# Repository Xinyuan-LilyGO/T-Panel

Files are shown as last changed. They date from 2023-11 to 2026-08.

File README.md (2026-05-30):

<h1 align="center">T-Panel</h1>

## **English** | [Chinese](./README_CN.md)

<!-- [![Release](https://img.shields.io/github/v/release/Xinyuan-LilyGO/T-Panel?style=flat-square)](https://github.com/Xinyuan-LilyGO/T-Panel/releases) -->




<p align="center">
  T-Panel product photo
</p>

## Overview

T-Panel is a compact smart-home control panel with an **ESP32-S3** main controller and a **480 x 480 RGB touch display**. It integrates local UI rendering, SD card storage, long-distance field-bus communication, and an **ESP32-H2** wireless coprocessor interface.

## Directory

- [Overview](#overview)
- [Hardware Versions](#hardware-versions)
- [Preview](#preview)
- [Supported Frameworks](#supported-frameworks)
- [Quick Start](#quick-start)
- [Hardware Modules](#hardware-modules)
- [Pin Overview](#pin-overview)
- [Project Materials](#project-materials)
- [FAQ](#faq)

## Hardware Versions

| Version | Date | Description |
| :---: | :---: | --- |
| T-Panel V1.0-V1.1 | 2023-11-23 | Initial hardware version |
| T-Panel V1.2 | 2023-12-11 | RS485 module changed to replaceable RS485/CAN module |
| T-Panel V1.3 | 2024-05-08 | Structure update |

## Preview

<p align="center">
  T-Panel front view
  T-Panel side view
  T-Panel back view
</p>

## Supported Frameworks

| Framework | Status | Version |
| --- | --- | --- |
| ESP-IDF | Recommended | `>= v5.5.4` |

## Quick Start

### Build With ESP-IDF

Install ESP-IDF first. For environment setup, refer to the official guide:
[ESP-IDF Get Started](https://docs.espressif.com/projects/esp-idf/en/latest/esp32s3/get-started/index.html)

```bash
idf.py set-target esp32s3
idf.py menuconfig
idf.py build
idf.py flash monitor
```

Select one of the following examples in `menuconfig`, then rebuild the project.

```text
Example Configuration
`-- Select the example to build
```

| Example | Description |
| --- | --- |
| [`screen`](./main/examples/screen) | Basic RGB LCD bring-up example |
| [`screen_lvgl`](./main/examples/screen_lvgl) | LVGL 9.5 display startup example |
| [`screen_lvgl_touch_draw`](./main/examples/screen_lvgl_touch_draw) | LVGL touch drawing example |
| [`sd`](./main/examples/sd) | SD card mount and file-system test |
| [`rs485_can`](./main/examples/rs485_can) | Field-bus transfer test example |
| [`general_test`](./main/examples/general_test) | Integrated factory test UI |

The following firmware is prebuilt.

To flash prebuilt firmware, refer to Espressif's official [ESP firmware online flashing platform guide](https://docs.espressif.com/projects/esp-techpedia/zh_CN/latest/esp-friends/get-started/try-firmware/try-firmware-platform.html).

| Firmware | Flash Address | Description |
| --- | --- | --- |
| [`general_test`](<./firmware/[t-panel_v1.2][general_test]>) | `0x0` | T-Panel V1.2 `general_test` factory test firmware |

## Hardware Modules

### 1. MCU

- MCU1: ESP32-S3
- PSRAM: 8 MB
- Flash: 16 MB
- Related documents:
  - [Espressif technical documents](https://www.espressif.com/en/support/documents/technical-documents)

- MCU2: ESP32-H2-MINI-1
- Flash: 4 MB
- Related documents:
  - [ESP32-H2-MINI-1 datasheet](https://www.espressif.com/sites/default/files/documentation/esp32-h2-mini-1_mini-1u_datasheet_en.pdf)

### 2. Display

- Model: YDP395BT001
- Size: 3.95 inch
- Resolution: 480 x 480
- Type: IPS
- Driver IC: ST7701S
- Bus: SPI initialization + RGB data bus
- Related documents:
  - [YDP395BT001-V2](./docs/YDP395BT001-V2.pdf)
  - [ST7701S](./docs/ST7701S_SPEC_V1.4.pdf)

### 3. Touch

- Chip: CST3240
- Bus: I2C
- Related documents:
  - [HYNITRON-CST3240_V1.0](./docs/HYNITRON-CST3240_V1.0.pdf)

### 4. IO Expansion

- Chip: XL9535
- Bus: I2C
- Usage: LCD reset/control, SPI control and auxiliary GPIO
- Related documents:
  - [XL9535](./docs/XL9535.pdf)

### 5. SD Card Slot

- Bus: SPI
- File system: FATFS

### 6. RS485 / CAN

- RS485 bus: UART
- CAN bus: TWAI
- Related documents:
  - [EBYTE-RSM485MT5V](./docs/EBYTE-RSM485MT5V.pdf)
  - [TD501MCANFD_MORNSUN](./docs/TD501MCANFD_MORNSUN.pdf)

> [!IMPORTANT]
> T-Panel V1.0-V1.1 ships with RS485 by default; T-Panel V1.2-V1.3 uses a replaceable RS485/CAN module.

## Pin Overview

Pin definitions are provided in [`t_panel_config.h`](./libraries/private_library/t_panel_config.h).

## Project Materials

| Document | Description |
| --- | --- |
| [`T-Panel_V1.2.pdf`](./project/T-Panel_V1.2.pdf) | Hardware project PDF |
| [`structure`](./structure) | Enclosure structure materials |

## FAQ

<details>
<summary>Q. Why does my board continuously fail to flash?</summary>

A. Please hold down the `BOOT` button and try downloading the program again.

</details>

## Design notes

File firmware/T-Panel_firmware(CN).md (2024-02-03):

<!--
 * @Description: None
 * @version: V1.0.0
 * @Author: LILYGO_L
 * @Date: 2023-09-12 18:12:36
 * @LastEditors: LILYGO_L
 * @LastEditTime: 2024-02-03 14:38:37
 * @License: GPL 3.0
-->
<h1 align = "center">T-Panel 初始测试 firmware 说明</h1>

## 适用版本：[T-Panel_V1.0]、[T-Panel_V1.1]
### <br />更改日志[ESP32S3]:
#### T-Panel_Test_ESP32S3_firmware_V1.0.0: 初始版本
#### T-Panel_Test_ESP32S3_firmware_V1.0.1:
    1.修复了整板重新上电后ESP32H2需要手动复位才有返回信息的问题
    2.修复了点击“Please touch me!”后进入主界面，屏幕出现大量ESP32H2初始化信息的问题
#### T-Panel_Test_ESP32S3_firmware_V1.0.2:
    1.新增屏幕边缘测试
#### T-Panel_Test_ESP32S3_firmware_V1.0.3:
    1.修复屏幕边缘测试部分时序不对检测失败的问题
#### T-Panel_Test_ESP32S3_firmware_V1.0.4:
    1.调整屏幕背光PWM为1Khz

### <br />更改日志[ESP32H2]:
#### T-Panel_Test_ESP32H2_firmware_V1.0.0: 初始版本
#### T-Panel_Test_ESP32H2_firmware_V1.0.1:
    1.修复了ESP32H2返回计数超过100后返回乱码的问题

## <br />适用版本：[T-Panel_V1.2]

### <br />更改日志[ESP32S3]:

#### [ESP32S3][T-Panel_V1.2][T-Panel_Test_V1_2]_firmware_V1.0.0(RS485): 初始版本

#### <br />[ESP32S3][T-Panel_V1.2][T-Panel_Test_V1_2]_firmware_V1.0.0(CAN): 初始版本

### <br />更改日志[ESP32H2]:
#### [ESP32H2][T-Panel_V1.2][ESP32H2_Test]_firmware_V1.0.2: 初始版本

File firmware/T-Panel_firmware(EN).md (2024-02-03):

<!--
 * @Description: None
 * @version: V1.0.0
 * @Author: LILYGO_L
 * @Date: 2023-09-12 18:12:36
 * @LastEditors: LILYGO_L
 * @LastEditTime: 2024-02-03 14:41:54
 * @License: GPL 3.0
-->
<h1 align = "center">T-Panel original testing firmware instructions</h1>

## Applicable Version: [T-Panel_V1.0],[T-Panel_V1.1]

### <br />Change Log[ESP32S3]:

#### T-Panel_Test_ESP32S3_firmware_V1.0.0: Original
#### T-Panel_Test_ESP32S3_firmware_V1.0.1:
    1. Fixed the issue of ESP32H2 needing manual reset after powering on the whole board again to return information.
    2. Fixed the problem of displaying a large number of ESP32H2 initialization messages on the screen after clicking "Please touch me!" and entering the main interface.
#### T-Panel_Test_ESP32S3_firmware_V1.0.2:
    1.Newly added screen edge testing
#### T-Panel_Test_ESP32S3_firmware_V1.0.3:
    1.Fix the issue of incorrect timing in the screen edge testing section and detection failure
#### T-Panel_Test_ESP32S3_firmware_V1.0.4:
    1.Adjust the screen backlight PWM to 1 Khz

### <br />Change Log[ESP32H2]:
#### T-Panel_Test_ESP32H2_firmware_V1.0.0: Original
#### T-Panel_Test_ESP32H2_firmware_V1.0.1:
    1. Fixed the issue of returning garbled characters when ESP32H2 returns a count exceeding 100.

## <br />Applicable Version: [T-Panel_V1.2]

### <br />Change Log[ESP32S3]:

#### [ESP32S3][T-Panel_V1.2][T-Panel_Test_V1_2]_firmware_V1.0.0(RS485): Original

#### <br />[ESP32S3][T-Panel_V1.2][T-Panel_Test_V1_2]_firmware_V1.0.0(CAN): Original

### <br />Change Log[ESP32H2]:
#### [ESP32H2][T-Panel_V1.2][ESP32H2_Test]_firmware_V1.0.2: Original

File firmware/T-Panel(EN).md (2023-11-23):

<!--
 * @Description: None
 * @version: V1.0.0
 * @Author: LILYGO_L
 * @Date: 2023-09-12 18:12:36
 * @LastEditors: LILYGO_L
 * @LastEditTime: 2023-11-23 15:03:34
 * @License: GPL 3.0
-->
## T-Panel instructions

### T-Panel_ESP32S3 Change Log:
#### T-Panel_Test_ESP32S3_firmware_V1.0.0:Original
#### T-Panel_Test_ESP32S3_firmware_V1.0.1:
    1. Fixed the issue of ESP32H2 needing manual reset after powering on the whole board again to return information.
    2. Fixed the problem of displaying a large number of ESP32H2 initialization messages on the screen after clicking "Please touch me!" and entering the main interface.

### T-Panel_Test_ESP32H2 Change Log:
#### T-Panel_Test_ESP32H2_firmware_V1.0.0:Original
#### T-Panel_Test_ESP32H2_firmware_V1.0.1:
    1. Fixed the issue of returning garbled characters when ESP32H2 returns a count exceeding 100.

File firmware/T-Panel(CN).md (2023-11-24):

<!--
 * @Description: None
 * @version: V1.0.0
 * @Author: LILYGO_L
 * @Date: 2023-09-12 18:12:36
 * @LastEditors: LILYGO_L
 * @LastEditTime: 2023-11-23 15:01:30
 * @License: GPL 3.0
-->
## T-Panel firmware 说明

### T-Panel_ESP32S3更改日志:
#### T-Panel_Test_ESP32S3_firmware_V1.0.0:初始版本
#### T-Panel_Test_ESP32S3_firmware_V1.0.1:
    1.修复了整板重新上电后ESP32H2需要手动复位才有返回信息的问题
    2.修复了点击“Please touch me!”后进入主界面，屏幕出现大量ESP32H2初始化信息的问题

### T-Panel_Test_ESP32H2更改日志:
#### T-Panel_Test_ESP32H2_firmware_V1.0.0:初始版本
#### T-Panel_Test_ESP32H2_firmware_V1.0.1:
    1.修复了ESP32H2返回计数超过100后返回乱码的问题

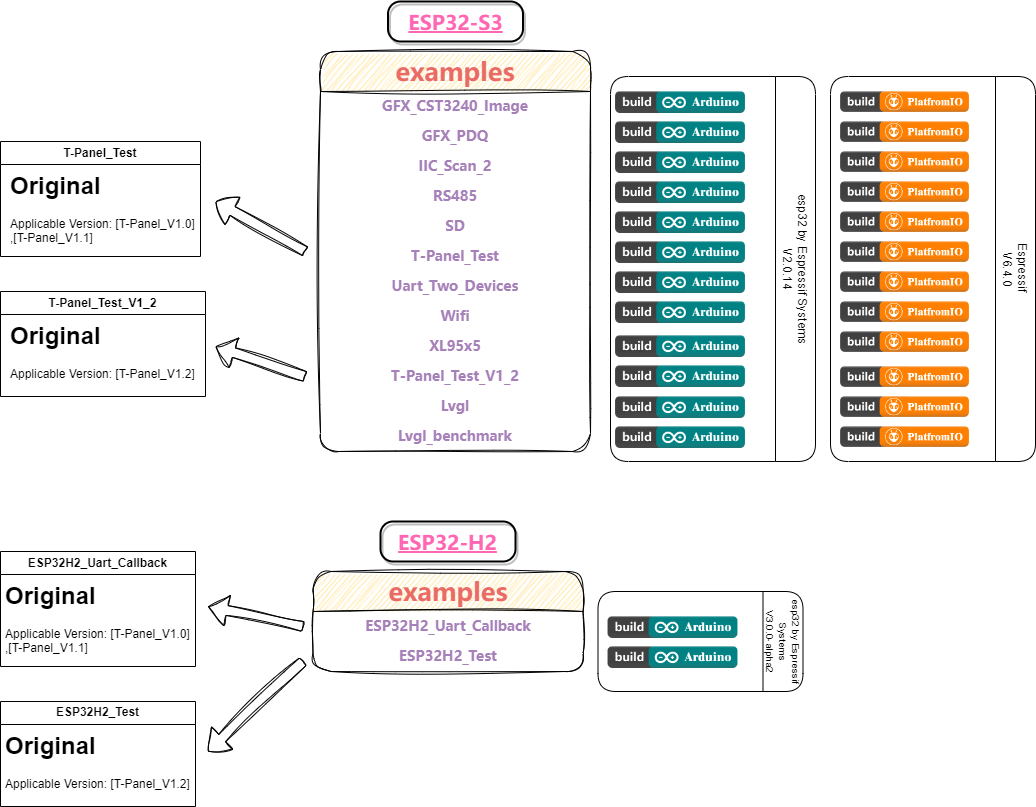
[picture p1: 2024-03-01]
image/T-Panel_Example_Support.png

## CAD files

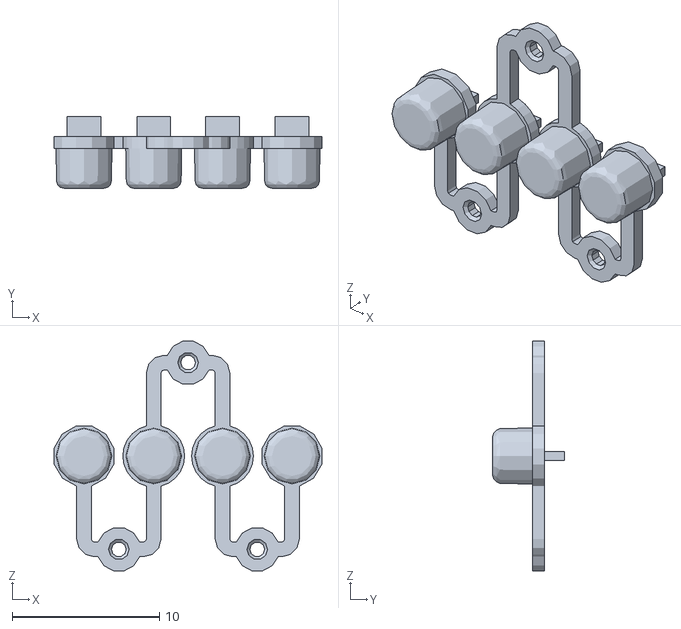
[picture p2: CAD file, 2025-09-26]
structure/T-Panel_shell_202509261512/4.stl
18.2 x 4.85 x 15.6

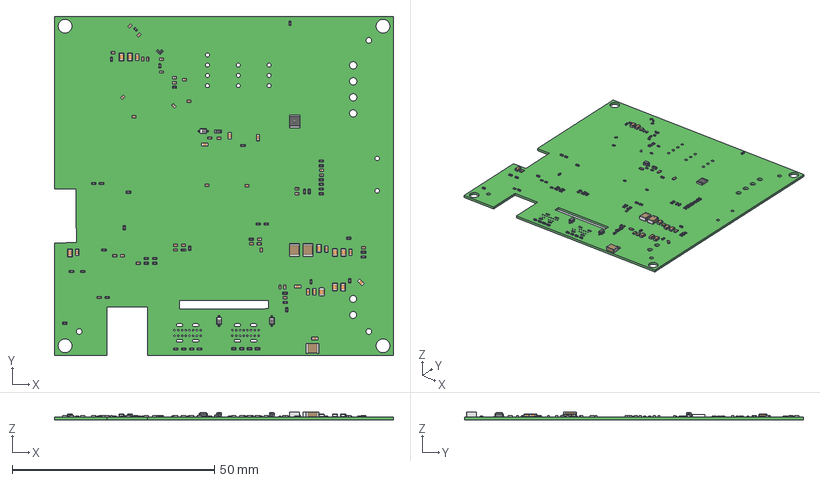
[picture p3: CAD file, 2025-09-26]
structure/T-Panel_V1.2.step
83.8 x 83.8 x 2.10 mm
L0402 x 3
0402_SMD_Capacitor x 37
User_Library-0603_SMD_Capacitor x 12
User_Library-0805_SMD_Capacitor x 9
User_Library-cap_1210_lowprofile x 3
User_Library-RES_1005-0402 x 47
SOD323 x 3
User_Library-RES_1609-0603
User_Library-R_1210

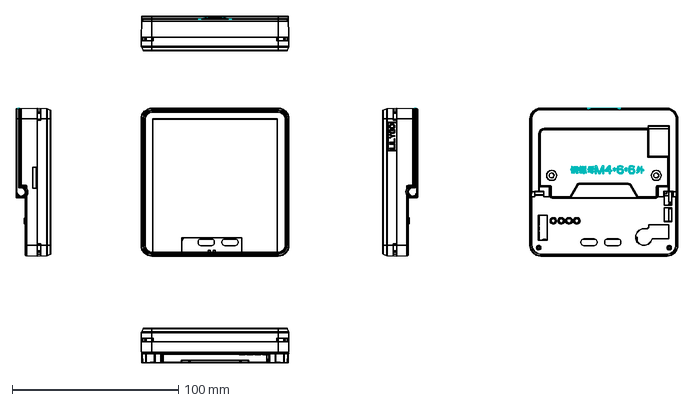
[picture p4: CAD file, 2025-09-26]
structure/T-Panel_shell.dxf
398.3 x 208.8 mm

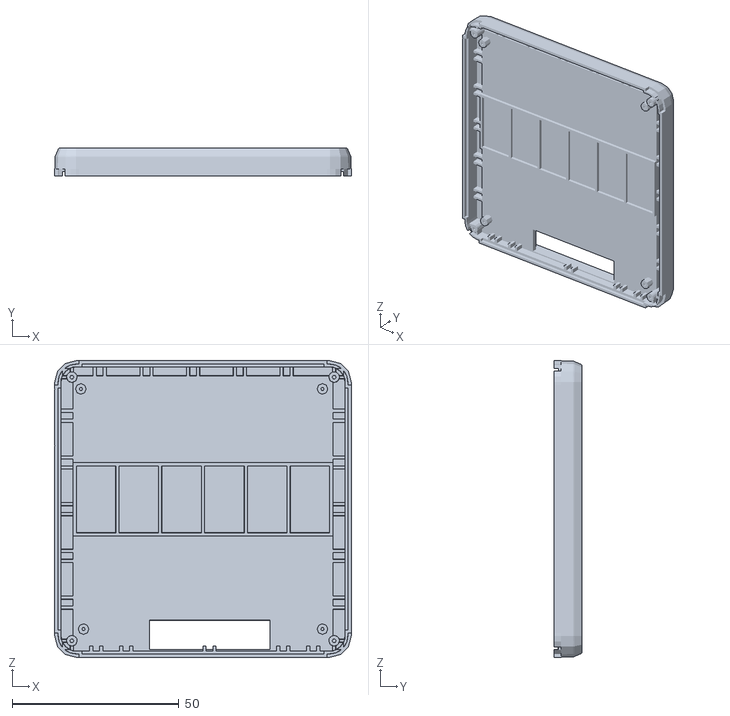
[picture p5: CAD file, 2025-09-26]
structure/T-Panel_shell_202509261512/1.stl
89.0 x 8.45 x 89.0

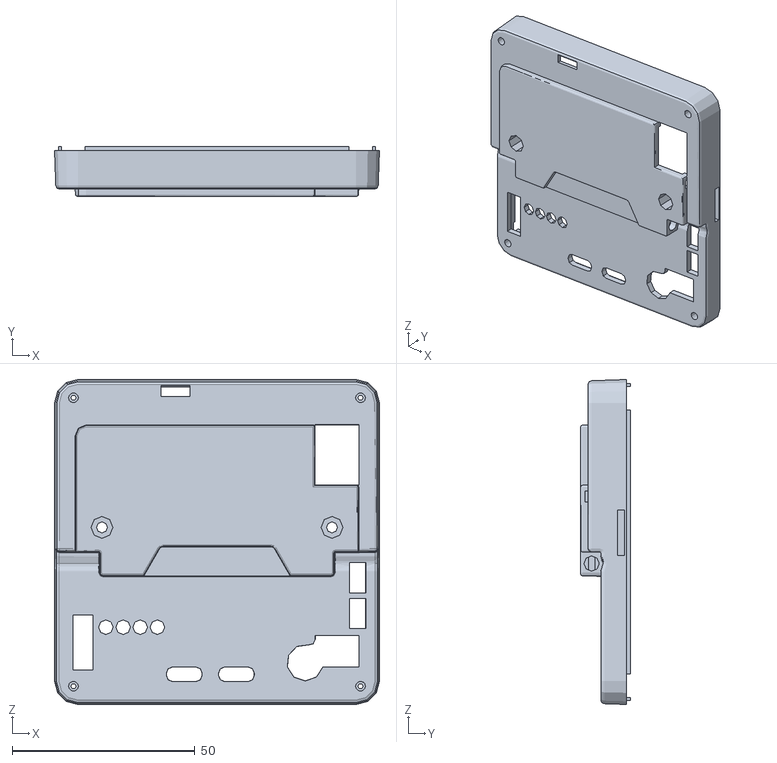
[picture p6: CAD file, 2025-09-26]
structure/T-Panel_shell_202509261512/2.stl
89.0 x 13.6 x 89.0

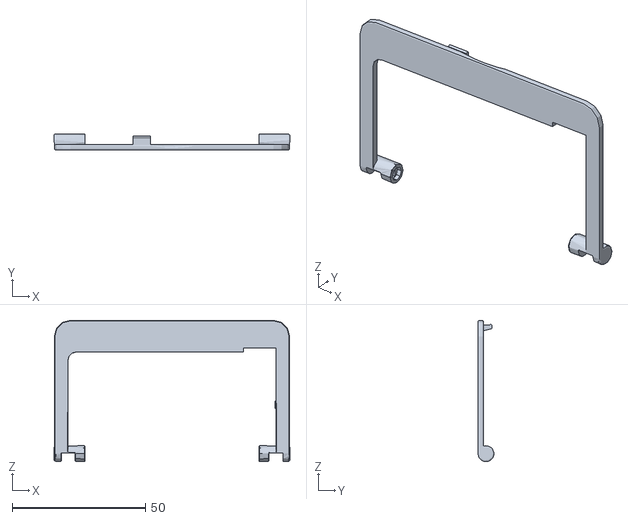
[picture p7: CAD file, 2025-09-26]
structure/T-Panel_shell_202509261512/3.stl
88.5 x 6.00 x 53.0

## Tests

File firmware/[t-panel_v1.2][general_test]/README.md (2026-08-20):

# Firmware Modification Log

## 202608200958
### Changed firmware
- `[t-panel_v1.2][general_test]_firmware_202608200958`
### Change content
- 修复can总线异常错误停止，防止can总线在正常通信连接的情况错误停止

## 202606131107
### Changed firmware
- `[t-panel_v1.2][general_test]_firmware_202606131107`
### Change content
- 删除rs485发送界面显示的无用crc error和seq error信息

## 202606131047
### Changed firmware
- `[t-panel_v1.2][general_test]_firmware_202606131047`
### Change content
- 将rs485校验数据改为使用crc16校验方式，修改rs485 can页面数据显示

## 202605301133
### Changed firmware
- `[t-panel_v1.2][general_test]_firmware_202605301133`
### Change content
- 新版本测试更新

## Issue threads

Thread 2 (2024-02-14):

Version?

Bwooce, 2024-02-14:
Got a shortcut so I can tell which board version I have? I assume since mine has no CAN then it's v1 or v1.1?  (I can't see any silkscreen version)

Llgok, 2024-02-29:
Two versions are currently available: T-Panel_V1.0 and T-Panel_V1.2 The hardware of the two versions is different, and the corresponding software is also different. You can find the relevant macro definitions in "./Mylibrary/pin_config.h"

1.T-Panel_V1.0 version only has an RS485 chip. Uncomment "#define T_Panel_V1_0_RS485".
2.T-Panel_V1.2 version can choose either an RS485 chip or a CAN bus chip based on the module inserted on the board. Uncomment "#define T_Panel_V1_2_RS485" or "#define T_Panel_V1_2_CAN" accordingly.

Llgok, 2024-02-29:
> Got a shortcut so I can tell which board version I have? I assume since mine has no CAN then it's v1 or v1.1? (I can't see any silkscreen version)

Two versions are currently available: T-Panel_V1.0 and T-Panel_V1.2 The hardware of the two versions is different, and the corresponding software is also different. You can find the relevant macro definitions in "./Mylibrary/pin_config.h"

1.T-Panel_V1.0 version only has an RS485 chip. Uncomment "#define T_Panel_V1_0_RS485".
2.T-Panel_V1.2 version can choose either an RS485 chip or a CAN bus chip based on the module inserted on the board. Uncomment "#define T_Panel_V1_2_RS485" or "#define T_Panel_V1_2_CAN" accordingly.

Bwooce, 2024-02-29:
Thanks! I have an RS485 version but not sure if it's 1.0 or 1.2, how can I tell? There's no version number written on the physical board?

Llgok, 2024-02-29:
> Thanks! I have an RS485 version but not sure if it's 1.0 or 1.2, how can I tell? There's no version number written on the physical board?

The replaceable long-distance transmission module is version 1.2.
The non-replaceable long-distance transmission module is version 1.0.

The following diagram is of version 1.2.
![Uploading IMG_20240229_175451.jpg…]()

Llgok, 2024-02-29:
> Thanks! I have an RS485 version but not sure if it's 1.0 or 1.2, how can I tell? There's no version number written on the physical board?

The replaceable long-distance transmission module is version 1.2.
The non-replaceable long-distance transmission module is version 1.0.

The following diagram is of version 1.2.
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

Closed 2024-05-07.

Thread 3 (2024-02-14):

RS485 information

Bwooce, 2024-02-14:
Small questions, after reading the RSM485 datasheet:
* S_GND is the isolated ground, so for RS485 GND wire?
* D_GND is for the outer cable shield? or for non-isolated RS485 GND?
* Is there a link to enable RS485 termination resistors? Or none on this board?

Nice board.

Llgok, 2024-02-29:
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

S_GND is the isolation voltage output negative pole of the module, usually used for connecting the ground wire of the signal line, mainly for transmitting data signals.
D_GND is the ground wire of the digital circuit, used to connect the ground wire in the digital circuit.

The T-Panel_V1.0 version module RSM485MT5V has built-in terminal resistance, so there is no need to connect terminal resistance on the PCB and externally.
The T-Panel_V1.2 version module does not have terminal resistance, so a 120-ohm terminal resistance is added to the PCB to ensure stable signal transmission.

Closed 2024-05-07.

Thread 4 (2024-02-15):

I2C Arduino MPC9600

neilaw, 2024-02-15:
I am trying to get the T-Panel to connect to an Adruino MPC9600 thermocouple amplifier without any success.
I can connect to other I2C devices ok, just not the Adafruit MPC9600.
I tried connecting the T-panel to a 24vdc power supply to see if it was a power issue, but it didn't make any diffrence.
Using the IIC Scanner, it momentarily showed the address. so it seems to be working, but not sure why it doesn't see it all the time.
I tried chenging the address in the MPC9600, but it didn't make any diffrence.
Any Ideas?

Llgok, 2024-02-29:
> Adruino MPC9600

Can you check if the power supply voltage for the MCP9600 device is normal?

Closed 2024-05-07.

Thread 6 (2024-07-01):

Readme needs clarification

manmountain, 2024-07-01:
I needed to install esp32 version 2.0.17 from boards manager to get the lvgl examples to build. That needs to be added to the readme.

And also, what is the recommended setting for Partition Scheme?

Llgok, 2024-07-10:
@manmountain
In the "QuickStart" section of the README.md file, the Partition Scheme is explained.

Closed 2024-07-19.

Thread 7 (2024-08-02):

CAD files available?

shyndman, 2024-08-02:
### IDE and version or firmware

n/a

### Operating System

n/a

### Description

Hello there,

I was wondering if you might release step files for the T-Panel's hardware variants. I'd really like to design some accurate cases for this thing. :)

PS. Thank you for the wonderful device. I'm having a lot of fun with it, and learning a lot.
PPS. Modelled a little leanback stand for use during development ([Printables link](https://www.printables.com/model/962461-lilygo-t-panel-s3-development-stand)), but without step files it's slightly wonky.

### Sketch

```cpp
n/a
```

### Debug Message

```plain
n/a
```

### Other steps to Reproduce

_No response_

Llgok, 2024-11-21:
@shyndman
Updated [T-Panel_V1.2 CAD](https://github.com/Xinyuan-LilyGO/T-Panel/blob/arduino-esp32-libs_V2.0.14/structure/T-Panel_V1.2.dxf) Drawings

Llgok, 2025-01-02:
Closed due to prolonged inactivity.

Closed 2025-01-02.

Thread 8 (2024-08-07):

Please clarify details on CANFD

TobyLies, 2024-08-07:
### IDE and version or firmware

T-Panel_V1.3 CANFD

### Operating System

T-Panel_V1.3 CANFD

### Description

Can you give some clarification on the CANFD version of the board? Is it CAN (Controller Area Network) or is it CAN FD (Flexible Data)? If it's CANFD, I gather that TWAI isn't compatible with CANFD?

I don't see any other reference to CANFD in the github.

I want to use the T-Panel to read CAN messages in a car, and display info derived from it. Does the T-Panel both send and receive CAN messages? Or does it require an external board?

### Sketch

```cpp
n/a
```

### Debug Message

```plain
n/a
```

### Other steps to Reproduce

_No response_

aokhrimenko, 2024-09-02:
What CAN transceiver do you use on this board? I see nothing on schematics.

viniciusro, 2024-09-02:
TD501MCANFD

Llgok, 2024-09-03:
> What CAN transceiver do you use on this board? I see nothing on schematics.

@aokhrimenko
@viniciusro
The following is the data manual for the CAN module.
[TD501MCANFD_MORNSUN](https://github.com/Xinyuan-LilyGO/T-Panel/blob/arduino-esp32-libs_V2.0.14/information/TD501MCANFD_MORNSUN.pdf)

Llgok, 2024-09-10:
Closed due to lack of response for a long time.

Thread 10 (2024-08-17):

Adding WIFI to Lvgl example will make it crash.

viniciusro, 2024-08-17:
### IDE and version or firmware

framework = arduino, platform = espressif32, board = dfrobot_firebeetle2_esp32s3

### Operating System

Windows 10

### Description

Adding simple wifi connect to setup will make the example crash:

### Sketch

```cpp
`    // Connect to Wi-Fi
    WiFi.mode(WIFI_MODE_STA);
    WiFi.begin(ssid, password);
    while (WiFi.status() != WL_CONNECTED)
    {
        delay(5);
        Serial.print(".");
    }
    Serial.println("Connected to WiFi");
    Serial.println(WiFi.localIP());`
```

### Debug Message

```plain
Ciallo
.................Connected to WiFi
192.168.188.75
Found xl9535
Guru Meditation Error: Core  1 panic'ed (LoadProhibited). Exception was unhandled.

Core  1 register dump:
PC      : 0x42005458  PS      : 0x00060f30  A0      : 0x82005575  A1      : 0x3fcebb50
A2      : 0x3fcebb74  A3      : 0xffffffff  A4      : 0x00000000  A5      : 0x000000ff
A6      : 0xffffffff  A7      : 0x000000ff  A8      : 0x820053b6  A9      : 0x3fcebb30
A10     : 0x00000000  A11     : 0x3fcebbc0  A12     : 0x3fcebbb8  A13     : 0x00000000
A14     : 0x00000001  A15     : 0x3fceba4c  SAR     : 0x0000001f  EXCCAUSE: 0x0000001c
EXCVADDR: 0x00000017  LBEG    : 0x400570e8  LEND    : 0x400570f3  LCOUNT  : 0x00000000

Backtrace: 0x42005455:0x3fcebb50 0x42005572:0x3fcebb70 0x42007473:0x3fcebbb0 0x42007c0b:0x3fcebc60 0x4209faa2:0x3fcebc90 0x420053c7:0x3fcebcb0 0x42005572:0x3fcebcd0 0x4200c5cd:0x3fcebd10 0x4200c699:0x3fcebd60 0x4200c9d2:0x3fcebde0 0x4200cb03:0x3fcebe10 0x4200d5bf:0x3fcebee0 0x420198e8:0x3fcebf30 0x420024c3:0x3fcebf60 0x4202db09:0x3fcebf80

ELF file SHA256: 20011c7cb8b2c78f

Rebooting...
ESP-ROM:esp32s3-20210327
Build:Mar 27 2021
rst:0xc (RTC_SW_CPU_RST),boot:0x8 (SPI_FAST_FLASH_BOOT)
Saved PC:0x420a232a
SPIWP:0xee
mode:DIO, clock div:1
load:0x3fce3808,len:0x4bc
load:0x403c9700,len:0xbd8
load:0x403cc700,len:0x2a0c
entry 0x403c98d0
```

### Other steps to Reproduce

After initialization and connection the WIFI is not used in any other place.
Same problem with "Lvgl_benchmark.ino"
As reference, with T-Encoder Pro, using lvgl and WIFI will work with no problem.

VolosR, 2024-08-23:
I have identical problem. Lvgl example will not work if board is connected to wifi.

nikthefix, 2024-08-24:
@viniciusro

As an experiment try replacing

lv_disp_draw_buf_init(&draw_buf, buf_1, buf_2, 48 * 1024 * 2);
with
lv_disp_draw_buf_init(&draw_buf, buf_1, NULL, 2 * 480 * 10);

nik

viniciusro, 2024-08-25:
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

Hey nik,

Thanks for the idea, it works!
Now I can sed UDP packages and display data on the screen.

I will investigate further the second buffer.

```cpp
    // lv_disp_draw_buf_init(&draw_buf, buf_1, buf_2, 48 * 1024 * 2);
    lv_disp_draw_buf_init(&draw_buf, buf_1, NULL, 2 * 480 * 10);
```

- draw_buf -- pointer lv_disp_draw_buf_t variable to initialize

- buf1 -- A buffer to be used by LVGL to draw the image. Always has to specified and can't be NULL. Can be an array allocated by the user. E.g. static lv_color_t disp_buf1[1024 * 10] Or a memory address e.g. in external SRAM

- buf2 -- Optionally specify a second buffer to make image rendering and image flushing (sending to the display) parallel. In the disp_drv->flush you should use DMA or similar hardware to send the image to the display in the background. It lets LVGL to render next frame into the other buffer while previous is being sent. Set to NULL if unused.

- size_in_px_cnt -- size of the buf1 and buf2 in pixel count.

nikthefix, 2024-08-25:
@viniciusro
Thanks for letting me know that it worked.
I made conservative assumptions as I didn't know how you defined your buf_1 but if you sized it to contain 16 bit/px then you could further reduce the lv draw buffer to just:

 lv_disp_draw_buf_init(&draw_buf, buf_1, NULL, 480 * 10); //single buffer, line px width, number of lines per write.

In my experience 10 to 40 lines per write is good use of resources for the 480x480 display and keeps things 'ticking' over nicely.
I have personally not seen any advantage to using double buffering with st7701 / esp32-s3 but your mileage may vary.

Volos Projects released a video this morning using the T-Panel:

https://www.youtube.com/watch?v=6-7ZjbE4Qqc

nik

Llgok, 2024-09-10:
Closed due to lack of response for a long time.

Closed 2024-09-10.

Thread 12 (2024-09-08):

Screen turns black every couple seconds when running the lvgl demo

8lue5ky, 2024-09-08:
### IDE and version or firmware

PlatformIO 6.1.15/3.4.4

### Operating System

Windows10

### Description

Hi

I downloaded this repo and uploaded the lvgl example (uncomment "default_envs = Lvgl" in platformIO).

The problem is that the screen turns black every couple of seconds when touching the screen. Same when trying to upload my own code from square line studio.

Interesting is that when the serial monitor is opened, it works correct (see "get_int" in the console when touching the screen).

Do you have any idea why this happens?

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

The Lvgl_benachmark works without issues, both, with and without serial monitor.

### Sketch

```cpp
Lvgl example from your repo T-Panel-arduino-esp32-libs_V2.0.14.
```

### Debug Message

```plain
None, because it doesn't happen when the serial monitor is opened.
```

### Other steps to Reproduce

_No response_

8lue5ky, 2024-09-08:
I found the issue.

When removing the `Serial.println("get_int");` in the `attachInterrupt()`, the issue is gone.

I assume that the `Serial.println` takes to much time in the interrupt handler.

Closed 2024-09-08.

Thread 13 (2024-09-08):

LVGL Switch click not working properly

8lue5ky, 2024-09-08:
### IDE and version or firmware

PlatformIO 6.1.15/3.4.4

### Operating System

Windows10

### Description

When using your LVGL file from the examples template as base with my own UI export files from square line studio, the toggle switch is somehow not working every time when clicked.

I made a small recording of the behavior:

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

It looks like the button is sometime clicked multiple times when touched once.

I saw that VolosR added some kind of debounce mechanism in his project [TPanelNetwork](https://github.com/VolosR/TPanelNetwork/blob/main/Panel/Panel.ino). But with that workaround, some other controls (e.g. Arc) are not really usable anymore.

Do you have any ideas how to improve this?

### Sketch

```cpp
Lvgl from examples folder with a toggle button.
```

### Debug Message

```plain
None.
```

### Other steps to Reproduce

_No response_

Llgok, 2024-09-10:
@8lue5ky
Hello, could you provide the code for the touch callback function in your LVGL project? Or, you could share the entire original file of your project, which would be more conducive to troubleshooting and resolving our issues.

8lue5ky, 2024-09-10:
I creates a copy of the Lvgl example with a screen just containing a toggle switch and a arc.

[Commit with example](https://github.com/8lue5ky/T-Panel/commit/4f4b5f497aa39810fa4b51a0713a6ffe2b73741b)

It should look like this:
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

Llgok, 2024-09-11:
@8lue5ky
I browsed through your code and found there were indeed issues with touch functionality. I've already fixed this problem. You can try replacing the following touch-related code:

```C++
/*Read the touchpad*/
void my_touchpad_read(lv_indev_drv_t *indev_drv, lv_indev_data_t *data)
{
    if (Touch_Int_Flag == true)
    {
        touch.read();
        TP_Point t = touch.getPoint(0);

        if ((touch.getPointNum() == 1) && (t.pressure > 0) && (t.state != 0))
        {
            data->state = LV_INDEV_STATE_PR;

            /*Set the coordinates*/
            data->point.x = t.x;
            data->point.y = t.y;

            // Serial.printf("Touch X: %d Y: %d", t.x, t.y);
            // Serial.printf("Static: %d", t.state);
            // Serial.printf("Pressure: %d", t.pressure);
        }

        Touch_Int_Flag = false;
    }
    else
    {
        data->state = LV_INDEV_STATE_REL;
    }
}
```

8lue5ky, 2024-09-12:
Thank you very much. It works now perfectly fine 👍

Closed 2024-09-12.

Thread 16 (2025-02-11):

STEP files for a custom enclosure

ArthurAfterBurnerDesign, 2025-02-11:
Hello,

I've find the dxf file in the enclosure [here](https://github.com/Xinyuan-LilyGO/T-Panel/blob/arduino-esp32-libs_V2.0.14/structure/T-Panel_V1.2.dxf), but can we please get a .step model of the enclosure and board, please ?

Thanks

Llgok, 2025-09-26:
@ArthurAfterBurnerDesign
This is the 3D image of the board. [T-Panel_V1.2.step](https://github.com/Xinyuan-LilyGO/T-Panel/blob/arduino-esp32-libs_V2.0.14/structure/T-Panel_V1.2.step)

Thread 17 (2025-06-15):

pin_config.h: No such file or directory

jsonslim, 2025-06-15:
### Operating System

Windows 10

### IDE

Arduino IDE

### Software Package Version

last versions

### Description

Hello, I'm trying to run the "Lvgl" example from  this repo. The first error message is "pin_config.h: No such file or directory".  I couldn't find this file anywhere in the repo/zip file. Please, add it - with the correct pin numbers and so on

### Sketch

```cpp
/*
 * @Description: LVGL
 * @Author: LILYGO_L
 * @Date: 2023-09-22 11:59:37
 * @LastEditTime: 2024-11-21 11:42:10
 * @License: GPL 3.0
 */
// #define TOUCH_MODULES_GT911
// #define TOUCH_MODULES_CST_SELF
#define TOUCH_MODULES_CST_MUTUAL
// #define TOUCH_MODULES_ZTW622
// #define TOUCH_MODULES_L58
// #define TOUCH_MODULES_FT3267
// #define TOUCH_MODULES_FT5x06

#include "lvgl.h"
#include "Arduino_GFX_Library.h"
#include "pin_config.h"
#include "TouchLib.h"
#include "gui_guider.h"
#include "events_init.h"
#include "custom.h"

volatile bool Touch_Int_Flag = false;

lv_ui guider_ui;

TouchLib touch(Wire, TOUCH_SDA, TOUCH_SCL, CST3240_ADDRESS);

Arduino_DataBus *bus = new Arduino_XL9535SWSPI(IIC_SDA /* SDA */, IIC_SCL /* SCL */, -1 /* XL PWD */,
                                               XL95X5_CS /* XL CS */, XL95X5_SCLK /* XL SCK */, XL95X5_MOSI /* XL MOSI */);
Arduino_ESP32RGBPanel *rgbpanel = new Arduino_ESP32RGBPanel(
    -1 /* DE */, LCD_VSYNC /* VSYNC */, LCD_HSYNC /* HSYNC */, LCD_PCLK /* PCLK */,
    LCD_B0 /* B0 */, LCD_B1 /* B1 */, LCD_B2 /* B2 */, LCD_B3 /* B3 */, LCD_B4 /* B4 */,
    LCD_G0 /* G0 */, LCD_G1 /* G1 */, LCD_G2 /* G2 */, LCD_G3 /* G3 */, LCD_G4 /* G4 */, LCD_G5 /* G5 */,
    LCD_R0 /* R0 */, LCD_R1 /* R1 */, LCD_R2 /* R2 */, LCD_R3 /* R3 */, LCD_R4 /* R4 */,
    1 /* hsync_polarity */, 20 /* hsync_front_porch */, 2 /* hsync_pulse_width */, 0 /* hsync_back_porch */,
    1 /* vsync_polarity */, 30 /* vsync_front_porch */, 8 /* vsync_pulse_width */, 1 /* vsync_back_porch */,
    10 /* pclk_active_neg */, 6000000L /* prefer_speed */, false /* useBigEndian */,
    0 /* de_idle_high*/, 0 /* pclk_idle_high */);
Arduino_RGB_Display *gfx = new Arduino_RGB_Display(
    LCD_WIDTH /* width */, LCD_HEIGHT /* height */, rgbpanel, 0 /* rotation */, true /* auto_flush */,
    bus, -1 /* RST */, st7701_type9_init_operations, sizeof(st7701_type9_init_operations));

static lv_disp_draw_buf_t draw_buf;
static lv_disp_drv_t disp_drv;

/* Display flushing */
void my_disp_flush(lv_disp_drv_t *disp, const lv_area_t *area, lv_color_t *color_p)
{
    uint32_t w = (area->x2 - area->x1 + 1);
    uint32_t h = (area->y2 - area->y1 + 1);

#if (LV_COLOR_16_SWAP != 0)
    gfx->draw16bitBeRGBBitmap(area->x1, area->y1, (uint16_t *)&color_p->full, w, h);
#else
    gfx->draw16bitRGBBitmap(area->x1, area->y1, (uint16_t *)&color_p->full, w, h);
#endif

    lv_disp_flush_ready(disp);
}

/*Read the touchpad*/
void my_touchpad_read(lv_indev_drv_t *indev_drv, lv_indev_data_t *data)
{
    if (Touch_Int_Flag == true)
    {
        touch.read();
        TP_Point t = touch.getPoint(0);

        if ((touch.getPointNum() == 1) && (t.pressure > 0) && (t.state != 0))
        {
            data->state = LV_INDEV_STATE_PR;

            /*Set the coordinates*/
            data->point.x = t.x;
            data->point.y = t.y;

            // Serial.printf("Touch X: %d Y: %d", t.x, t.y);
            // Serial.printf("Static: %d", t.state);
            // Serial.printf("Pressure: %d", t.pressure);
        }

        Touch_Int_Flag = false;
    }
    else
    {
        data->state = LV_INDEV_STATE_REL;
    }
}

void lvgl_initialization(void)
{
    lv_init();

    uint32_t screen_width = gfx->width();
    uint32_t screen_height = gfx->height();

    // 使用PSRAM分配内存
    lv_color_t *buf_1 = (lv_color_t *)heap_caps_malloc(sizeof(lv_color_t) * LCD_WIDTH * 40, MALLOC_CAP_INTERNAL | MALLOC_CAP_8BIT);
    lv_color_t *buf_2 = (lv_color_t *)heap_caps_malloc(sizeof(lv_color_t) * LCD_WIDTH * 40, MALLOC_CAP_INTERNAL | MALLOC_CAP_8BIT);

    while ((!buf_1) || (!buf_2))
    {
        Serial.println("LVGL disp_draw_buf allocate failed!");
        delay(1000);
    }

    lv_disp_draw_buf_init(&draw_buf, buf_1, buf_2, LCD_WIDTH * 40);

    /* Initialize the display */
    lv_disp_drv_init(&disp_drv);
    /* Change the following line to your display resolution */
    disp_drv.hor_res = screen_width;
    disp_drv.ver_res = screen_height;
    disp_drv.flush_cb = my_disp_flush;
    disp_drv.draw_buf = &draw_buf;
    disp_drv.full_refresh = 1; // 双缓冲全像素刷新
    lv_disp_drv_register(&disp_drv);

    /*Initialize the (dummy) input device driver*/
    static lv_indev_drv_t indev_drv;
    lv_indev_drv_init(&indev_drv);
    indev_drv.type = LV_INDEV_TYPE_POINTER;
    indev_drv.read_cb = my_touchpad_read;
    lv_indev_drv_register(&indev_drv);
}

void setup()
{
    Serial.begin(115200);
    Serial.println("Ciallo");

    pinMode(LCD_BL, OUTPUT);
    digitalWrite(LCD_BL, HIGH);

    attachInterrupt(
        TOUCH_INT,
        []
        {
            Touch_Int_Flag = true;
            // Serial.println("get_int");
        },
        FALLING);

    Wire.begin(IIC_SDA, IIC_SCL);

    gfx->begin();
    gfx->fillScreen(BLACK);

    gfx->XL_digitalWrite(XL95X5_TOUCH_RST, LOW);
    delay(200);
    gfx->XL_digitalWrite(XL95X5_TOUCH_RST, HIGH);
    delay(200);

    touch.init();

    lvgl_initialization();

    setup_ui(&guider_ui);
    events_init(&guider_ui);
}

void loop()
{
    lv_timer_handler(); /* let the GUI do its work */
    delay(5);
}
```

### Debug Message

```plain
...\T-Panel-arduino-esp32-libs_V2.0.14\examples\Lvgl\Lvgl.ino:18:10: fatal error: pin_config.h: No such file or directory
   18 | #include "pin_config.h"
      |          ^~~~~~~~~~~~~~
compilation terminated.
exit status 1

Compilation error: pin_config.h: No such file or directory
```

### Other steps to Reproduce

Download the zip file of the repo -> open the Lvgl.ino from the examples folder -> compile

jsonslim, 2025-06-15:
UPD. I added libraries folder to the sketch location as described in the readme, but there are still errors: `D:\hardware_projects\WORK\PAULUS\T-Panel-arduino-esp32-libs_V2.0.14\examples\Lvgl\setup_scr_screen.c: In function 'setup_scr_screen':
D:\hardware_projects\WORK\PAULUS\T-Panel-arduino-esp32-libs_V2.0.14\examples\Lvgl\setup_scr_screen.c:53:33: error: implicit declaration of function 'lv_carousel_create'; did you mean 'lv_canvas_create'? [-Wimplicit-function-declaration]
   53 |         ui->screen_carousel_1 = lv_carousel_create(ui->screen);
      |                                 ^~~~~~~~~~~~~~~~~~
      |                                 lv_canvas_create
D:\hardware_projects\WORK\PAULUS\T-Panel-arduino-esp32-libs_V2.0.14\examples\Lvgl\setup_scr_screen.c:53:31: error: assignment to 'lv_obj_t *' {aka 'struct _lv_obj_t *'} from 'int' makes pointer from integer without a cast [-Wint-conversion]
   53 |         ui->screen_carousel_1 = lv_carousel_create(ui->screen);
      |                               ^
D:\hardware_projects\WORK\PAULUS\T-Panel-arduino-esp32-libs_V2.0.14\examples\Lvgl\setup_scr_screen.c:54:9: error: implicit declaration of function 'lv_carousel_set_element_width' [-Wimplicit-function-declaration]
   54 |         lv_carousel_set_element_width(ui->screen_carousel_1, 300);
      |         ^~~~~~~~~~~~~~~~~~~~~~~~~~~~~
D:\hardware_projects\WORK\PAULUS\T-Panel-arduino-esp32-libs_V2.0.14\examples\Lvgl\setup_scr_screen.c:56:43: error: implicit declaration of function 'lv_carousel_add_element' [-Wimplicit-function-declaration]
   56 |         ui->screen_carousel_1_element_1 = lv_carousel_add_element(ui->screen_carousel_1, 0);
      |                                           ^~~~~~~~~~~~~~~~~~~~~~~
D:\hardware_projects\WORK\PAULUS\T-Panel-arduino-esp32-libs_V2.0.14\examples\Lvgl\setup_scr_screen.c:56:41: error: assignment to 'lv_obj_t *' {aka 'struct _lv_obj_t *'} from 'int' makes pointer from integer without a cast [-Wint-conversion]
   56 |         ui->screen_carousel_1_element_1 = lv_carousel_add_element(ui->screen_carousel_1, 0);
      |                                         ^
D:\hardware_projects\WORK\PAULUS\T-Panel-arduino-esp32-libs_V2.0.14\examples\Lvgl\setup_scr_screen.c:57:41: error: assignment to 'lv_obj_t *' {aka 'struct _lv_obj_t *'} from 'int' makes pointer from integer without a cast [-Wint-conversion]
   57 |         ui->screen_carousel_1_element_2 = lv_carousel_add_element(ui->screen_carousel_1, 1);
      |                                         ^
D:\hardware_projects\WORK\PAULUS\T-Panel-arduino-esp32-libs_V2.0.14\examples\Lvgl\setup_scr_screen.c:58:41: error: assignment to 'lv_obj_t *' {aka 'struct _lv_obj_t *'} from 'int' makes pointer from integer without a cast [-Wint-conversion]
   58 |         ui->screen_carousel_1_element_3 = lv_carousel_add_element(ui->screen_carousel_1, 2);
      |                                         ^
D:\hardware_projects\WORK\PAULUS\T-Panel-arduino-esp32-libs_V2.0.14\examples\Lvgl\setup_scr_screen.c:59:41: error: assignment to 'lv_obj_t *' {aka 'struct _lv_obj_t *'} from 'int' makes pointer from integer without a cast [-Wint-conversion]
   59 |         ui->screen_carousel_1_element_4 = lv_carousel_add_element(ui->screen_carousel_1, 3);
      |                                         ^
D:\hardware_projects\WORK\PAULUS\T-Panel-arduino-esp32-libs_V2.0.14\examples\Lvgl\Lvgl.ino:28:22: error: 'TOUCH_SDA' was not declared in this scope; did you mean 'TOUCH_PAD_MAX'?
   28 | TouchLib touch(Wire, TOUCH_SDA, TOUCH_SCL, CST3240_ADDRESS);
      |                      ^~~~~~~~~
      |                      TOUCH_PAD_MAX
D:\hardware_projects\WORK\PAULUS\T-Panel-arduino-esp32-libs_V2.0.14\examples\Lvgl\Lvgl.ino:28:33: error: 'TOUCH_SCL' was not declared in this scope
   28 | TouchLib touch(Wire, TOUCH_SDA, TOUCH_SCL, CST3240_ADDRESS);
      |                                 ^~~~~~~~~
D:\hardware_projects\WORK\PAULUS\T-Panel-arduino-esp32-libs_V2.0.14\examples\Lvgl\Lvgl.ino:28:44: error: 'CST3240_ADDRESS' was not declared in this scope
   28 | TouchLib touch(Wire, TOUCH_SDA, TOUCH_SCL, CST3240_ADDRESS);
      |                                            ^~~~~~~~~~~~~~~
D:\hardware_projects\WORK\PAULUS\T-Panel-arduino-esp32-libs_V2.0.14\examples\Lvgl\Lvgl.ino:30:48: error: 'IIC_SDA' was not declared in this scope
   30 | Arduino_DataBus *bus = new Arduino_XL9535SWSPI(IIC_SDA /* SDA */, IIC_SCL /* SCL */, -1 /* XL PWD */,
      |                                                ^~~~~~~
D:\hardware_projects\WORK\PAULUS\T-Panel-arduino-esp32-libs_V2.0.14\examples\Lvgl\Lvgl.ino:30:67: error: 'IIC_SCL' was not declared in this scope
   30 | Arduino_DataBus *bus = new Arduino_XL9535SWSPI(IIC_SDA /* SDA */, IIC_SCL /* SCL */, -1 /* XL PWD */,
      |                                                                   ^~~~~~~
D:\hardware_projects\WORK\PAULUS\T-Panel-arduino-esp32-libs_V2.0.14\examples\Lvgl\Lvgl.ino:31:48: error: 'XL95X5_CS' was not declared in this scope
   31 |                                                XL95X5_CS /* XL CS */, XL95X5_SCLK /* XL SCK */, XL95X5_MOSI /* XL MOSI */);
      |                                                ^~~~~~~~~
D:\hardware_projects\WORK\PAULUS\T-Panel-arduino-esp32-libs_V2.0.14\examples\Lvgl\Lvgl.ino:31:71: error: 'XL95X5_SCLK' was not declared in this scope
   31 |                                                XL95X5_CS /* XL CS */, XL95X5_SCLK /* XL SCK */, XL95X5_MOSI /* XL MOSI */);
      |                                                                       ^~~~~~~~~~~
D:\hardware_projects\WORK\PAULUS\T-Panel-arduino-esp32-libs_V2.0.14\examples\Lvgl\Lvgl.ino:31:97: error: 'XL95X5_MOSI' was not declared in this scope
   31 |                                                XL95X5_CS /* XL CS */, XL95X5_SCLK /* XL SCK */, XL95X5_MOSI /* XL MOSI */);
      |                                                                                                 ^~~~~~~~~~~
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

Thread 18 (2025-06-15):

Misleading pin definition / overview

jsonslim, 2025-06-15:
The display pins review in the readme section doesn't match the pins on the schematic diagram. Please fix

jsonslim, 2025-06-15:
`<html><body>
<!--StartFragment--><div class="markdown-heading" dir="auto"><h2 tabindex="-1" class="heading-element" dir="auto">PinOverview</h2><a id="user-content-pinoverview" class="anchor" aria-label="Permalink: PinOverview" href="https://github.com/Xinyuan-LilyGO/T-Panel#pinoverview"><svg class="octicon octicon-link" viewBox="0 0 16 16" version="1.1" width="16" height="16" aria-hidden="true"></svg></a></div>
Display Pin | ESP32S3 Pin | XL95X5 Pin
-- | -- | --
VSYNC | ESP32S3_IO40 | NULL
HSYNC | ESP32S3_IO39 | NULL
PCLK | ESP32S3_IO41 | NULL
B0 | ESP32S3_IO1 | NULL
B1 | ESP32S3_IO2 | NULL
B2 | ESP32S3_IO3 | NULL
B3 | ESP32S3_IO4 | NULL
B4 | ESP32S3_IO5 | NULL
G0 | ESP32S3_IO6 | NULL
G1 | ESP32S3_IO7 | NULL
G2 | ESP32S3_IO8 | NULL
G3 | ESP32S3_IO9 | NULL
G4 | ESP32S3_IO10 | NULL
G5 | ESP32S3_IO11 | NULL
R0 | ESP32S3_IO12 | NULL
R1 | ESP32S3_IO13 | NULL
R2 | ESP32S3_IO42 | NULL
R3 | ESP32S3_IO46 | NULL
R4 | ESP32S3_ IO45 | NULL
BL | ESP32S3_IO14 | NULL
CS | NULL | XL95X5_IO17
SCLK | NULL | XL95X5_IO15
MOSI | NULL | XL95X5_IO16
RST | NULL | XL95X5_IO5

<!--EndFragment-->
</body>
</html>`

Llgok, 2025-06-21:
@jsonslim
Hello, the pin definition shall be based on the configuration in the software. [pin_config.h](https://github.com/Xinyuan-LilyGO/T-Panel/blob/arduino-esp32-libs_V2.0.14/libraries/Mylibrary/pin_config.h)

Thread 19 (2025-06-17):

CAN version Guru Meditation Error: Core  1 panic'ed

jsonslim, 2025-06-17:
### Operating System

Win 10

### IDE

Arduino

### Software Package Version

ESP32 core v2.x

### Description

I have `Guru Meditation Error: Core  1 panic'ed (Interrupt wdt timeout on CPU1). `  error when I touch the display, Sometimes the errors appears suddenly.

I found out the there is the pin conflict:

// XL95x5
#define XL95X5_SCLK 15
#define XL95X5_MOSI 16

#if defined T_Panel_V1_2_CAN
#define CAN_TX 16
#define CAN_RX 15
#endif

### Sketch

```cpp
/*
 * @Description: T-Panel_V1.2出厂测试程序
 * @Author: LILYGO_L
 * @Date: 2023-09-16 10:47:28
 * @LastEditTime: 2024-06-04 10:10:27
 * @License: GPL 3.0
 */
// #define TOUCH_MODULES_GT911
// #define TOUCH_MODULES_CST_SELF
#define TOUCH_MODULES_CST_MUTUAL
// #define TOUCH_MODULES_ZTW622
// #define TOUCH_MODULES_L58
// #define TOUCH_MODULES_FT3267
// #define TOUCH_MODULES_FT5x06

#include <Arduino.h>
#include "lvgl.h"
#include <Arduino_GFX_Library.h>
#include <Wire.h>
#include <SPI.h>
#include <SD.h>
#include <HardwareSerial.h>
#include "TouchLib.h"
#include "Material_16Bit_480x480px.h"
#include "pin_config.h"
#include <WiFi.h>
#include <HTTPClient.h>
#include <driver/twai.h>

// #define WIFI_SSID "LilyGo-AABB"
// #define WIFI_PASSWORD "xinyuandianzi"

bool Get_int = 0;
uint8_t Image_Flag = 0;
bool Touch_Flag = 0;
uint8_t Touch_Num = 0;

uint8_t Last_X = 0;
uint8_t Last_Y = 0;

HardwareSerial SerialPort1(1);  // use UART1

#if defined T_Panel_V1_2_RS485
HardwareSerial SerialPort2(2);  // use UART2
#endif

char DATA1[100] = { 0 };
uint8_t GFX_Print_Uart_Cursor = 0;
bool Uart_Start = 0;
uint32_t Uart_Count = 0;
size_t cycleInterval = 0;
bool wifi_connection_failure_flag = false;
uint32_t wifi_time_delay = 0;
static uint8_t gfx_rotation = 2;

TouchLib touch(Wire, IIC_SDA, IIC_SCL, CST3240_ADDRESS);

Arduino_DataBus *bus = new Arduino_XL9535SWSPI(IIC_SDA /* SDA */, IIC_SCL /* SCL */, -1 /* XL PWD */,
                                               XL95X5_CS /* XL CS */, XL95X5_SCLK /* XL SCK */, XL95X5_MOSI /* XL MOSI */);

Arduino_ESP32RGBPanel *rgbpanel = new Arduino_ESP32RGBPanel(
  -1 /* DE */, LCD_VSYNC /* VSYNC */, LCD_HSYNC /* HSYNC */, LCD_PCLK /* PCLK */,
  LCD_B0 /* B0 */, LCD_B1 /* B1 */, LCD_B2 /* B2 */, LCD_B3 /* B3 */, LCD_B4 /* B4 */,
  LCD_G0 /* G0 */, LCD_G1 /* G1 */, LCD_G2 /* G2 */, LCD_G3 /* G3 */, LCD_G4 /* G4 */, LCD_G5 /* G5 */,
  LCD_R0 /* R0 */, LCD_R1 /* R1 */, LCD_R2 /* R2 */, LCD_R3 /* R3 */, LCD_R4 /* R4 */,
  1 /* hsync_polarity */, 20 /* hsync_front_porch */, 2 /* hsync_pulse_width */, 0 /* hsync_back_porch */,
  1 /* vsync_polarity */, 30 /* vsync_front_porch */, 8 /* vsync_pulse_width */, 1 /* vsync_back_porch */,
  10 /* pclk_active_neg */, 6000000L /* prefer_speed */, false /* useBigEndian */,
  0 /* de_idle_high*/, 0 /* pclk_idle_high */);
Arduino_RGB_Display *gfx = new Arduino_RGB_Display(
  LCD_WIDTH /* width */, LCD_HEIGHT /* height */, rgbpanel, 2 /* rotation */, true /* auto_flush */,
  bus, -1 /* RST */, st7701_type9_init_operations, sizeof(st7701_type9_init_operations));

#if defined T_Panel_V1_2_CAN
void CAN_Drive_Initialization() {
  // Initialize configuration structures using macro initializers
  twai_general_config_t g_config = TWAI_GENERAL_CONFIG_DEFAULT((gpio_num_t)CAN_TX, (gpio_num_t)CAN_RX, TWAI_MODE_NORMAL);
  twai_timing_config_t t_config = TWAI_TIMING_CONFIG_500KBITS();
  twai_filter_config_t f_config = TWAI_FILTER_CONFIG_ACCEPT_ALL();

  // Install TWAI driver
  if (twai_driver_install(&g_config, &t_config, &f_config) == ESP_OK) {
    Serial.println("Driver installed");
  } else {
    Serial.println("Failed to install driver");
  }

  // Start TWAI driver
  if (twai_start() == ESP_OK) {
    Serial.println("Driver started");
  } else {
    Serial.println("Failed to start driver");
  }

  // Configuration
  uint32_t alerts_to_enable = TWAI_ALERT_TX_IDLE | TWAI_ALERT_TX_SUCCESS | TWAI_ALERT_TX_FAILED | TWAI_ALERT_ERR_PASS | TWAI_ALERT_BUS_ERROR | TWAI_ALERT_RX_DATA | TWAI_ALERT_RX_QUEUE_FULL;

  if (twai_reconfigure_alerts(alerts_to_enable, NULL) == ESP_OK) {
    Serial.println("CAN Alerts reconfigured");
  } else {
    Serial.println("Failed to reconfigure alerts");
  }
}

void Twai_Send_Message() {
  // Configure message to transmit
  twai_message_t message;
  message.identifier = 0x0F6;
  message.data_length_code = 1;
  message.data[0] = Uart_Count;

  // Queue message for transmission
  if (twai_transmit(&message, pdMS_TO_TICKS(1000)) == ESP_OK) {
    printf("Message queued for transmission\n");
  } else {
    printf("Failed to queue message for transmission\n");
  }
}

void Twai_Receive_Message(twai_message_t &message) {
  // Process received message
  if (message.extd) {
    Serial.println("Message is in Extended Format");
  } else {
    Serial.println("Message is in Standard Format");
  }
  Serial.printf("ID: %x\nByte:", message.identifier);
  if (!(message.rtr)) {
    for (int i = 0; i < message.data_length_code; i++) {
      Serial.printf(" %d = %02x,", i, message.data[i]);
    }
    Serial.println("");
  }
}
#endif

void scan_i2c_device(TwoWire &i2c) {
  Serial.println("Scanning for I2C devices ...");
  Serial.print("      ");
  for (int i = 0; i < 0x10; i++) {
    Serial.printf("0x%02X|", i);
  }
  uint8_t error;
  for (int j = 0; j < 0x80; j += 0x10) {
    Serial.println();
    Serial.printf("0x%02X |", j);
    for (int i = 0; i < 0x10; i++) {
      Wire.beginTransmission(i | j);
      error = Wire.endTransmission();
      if (error == 0)
        Serial.printf("0x%02X|", i | j);
      else
        Serial.print(" -- |");
    }
  }
  Serial.println();
}

void setup() {
  Serial.begin(115200);
  Serial.println("Ciallo");

  SerialPort1.begin(115200, SERIAL_8N1, ESP32H2_RX, ESP32H2_TX);

#if defined T_Panel_V1_2_RS485
  SerialPort2.begin(115200, SERIAL_8N1, RS485_RX, RS485_TX);
#endif

#if defined T_Panel_V1_2_CAN
  CAN_Drive_Initialization();
#endif

  pinMode(0, INPUT_PULLUP);

  pinMode(ESP32H2_BOOT, OUTPUT);
  digitalWrite(ESP32H2_BOOT, HIGH);

  pinMode(ESP32H2_EN, OUTPUT);
  digitalWrite(ESP32H2_EN, LOW);

  pinMode(LCD_BL, OUTPUT);
  digitalWrite(LCD_BL, LOW);

  pinMode(TOUCH_INT, INPUT_PULLUP);
  digitalWrite(TOUCH_INT, HIGH);

  attachInterrupt(
    TOUCH_INT,
    [] {
      Get_int = 1;
      Serial.println("get_int");
    },
    FALLING);  // Triggered every 1ms

  ledcAttachPin(LCD_BL, 1);
  ledcSetup(1, 1000, 8);
  ledcWrite(1, 0);

  Wire.begin(IIC_SDA, IIC_SCL);
  // scan_i2c_device(Wire);

  gfx->begin();
  gfx->setRotation(2);
  gfx->fillScreen(WHITE);

  // adjusting display brightness
  for (int i = 0; i <= 255; i++) {
    ledcWrite(1, i);
    delay(2);
  }

  // Touch
  gfx->XL_digitalWrite(XL95X5_TOUCH_RST, LOW);
  delay(200);
  gfx->XL_digitalWrite(XL95X5_TOUCH_RST, HIGH);
  delay(200);

  gfx->XL_digitalWrite(XL95X5_RS485_CON, HIGH);

  touch.init();

  gfx->XL_pinMode(XL95X5_ESP32H2_IO12, OUTPUT);
  gfx->XL_digitalWrite(XL95X5_ESP32H2_IO12, LOW);

  gfx->XL_pinMode(XL95X5_ESP32H2_IO4, INPUT);
  gfx->XL_pinMode(XL95X5_ESP32H2_IO5, INPUT);

  gfx->fillScreen(BLACK);
  gfx->setCursor(0, 0);

  touch.read();
  TP_Point t = touch.getPoint(0);
  Last_X = t.x;
  Last_Y = t.y;

  gfx->fillScreen(WHITE);
  gfx->setCursor(100, 200);
  gfx->setTextSize(3);
  gfx->setTextColor(PURPLE);
  gfx->printf("Touch to run");
}

void loop() {
  if (digitalRead(0) == LOW) {
    delay(30);

    gfx->draw16bitRGBBitmap(0, 0, (uint16_t *)gImage_1, 480, 480);

    gfx->fillRect(230, 330, 280, 150, BLACK);
    gfx->setCursor(265, 340);
    gfx->setTextSize(2);
    gfx->setTextColor(BLUE);
    gfx->printf("UART Information");
  }

  if (Uart_Start == 1) {
#if defined T_Panel_V1_2_CAN
    // Bus status information
    twai_status_info_t twai_status_info;
    twai_get_status_info(&twai_status_info);
    // Communication alarm detection
    uint32_t alerts_triggered;
    twai_read_alerts(&alerts_triggered, pdMS_TO_TICKS(1000));

    switch (alerts_triggered) {
      case TWAI_ALERT_ERR_PASS:
        Serial.println("\nAlert: TWAI controller has become error passive.");
        break;
      case TWAI_ALERT_BUS_ERROR:
        Serial.println("\nAlert: A (Bit, Stuff, CRC, Form, ACK) error has occurred on the bus.");
        Serial.printf("Bus error count: %d\n", twai_status_info.bus_error_count);
        break;
      case TWAI_ALERT_TX_FAILED:
        Serial.println("\nAlert: The Transmission failed.");
        Serial.printf("TX buffered: %d\t", twai_status_info.msgs_to_tx);
        Serial.printf("TX error: %d\t", twai_status_info.tx_error_counter);
        Serial.printf("TX failed: %d\n", twai_status_info.tx_failed_count);
        break;
      case TWAI_ALERT_TX_SUCCESS:
        Serial.println("\nAlert: The Transmission was successful.");
        Serial.printf("TX buffered: %d\t", twai_status_info.msgs_to_tx);
        break;
      case TWAI_ALERT_RX_QUEUE_FULL:
        Serial.println("\nAlert: The RX queue is full causing a received frame to be lost.");
        Serial.printf("RX buffered: %d\t", twai_status_info.msgs_to_rx);
        Serial.printf("RX missed: %d\t", twai_status_info.rx_missed_count);
        Serial.printf("RX overrun %d\n", twai_status_info.rx_overrun_count);
        break;

      default:
        break;
    }
#endif

    if (millis() > cycleInterval) {
      Uart_Count++;
      gfx->setCursor(250, 360 + GFX_Print_Uart_Cursor);
      gfx->setTextSize(1);
      gfx->setTextColor(CYAN);

      gfx->setTextColor(YELLOW);
      gfx->printf("TX-> ");
      gfx->setTextColor(CYAN);
      gfx->printf("ESP32S3 to ESP32H2:%d", Uart_Count);

      GFX_Print_Uart_Cursor += 10;
      if (GFX_Print_Uart_Cursor > 130) {
        GFX_Print_Uart_Cursor = 0;
        gfx->fillRect(230, 330, 280, 150, BLACK);
        gfx->setCursor(265, 340);
        gfx->setTextSize(2);
        gfx->setTextColor(BLUE);
        gfx->printf("UART Information");
      }

#if defined T_Panel_V1_2_RS485
      gfx->setCursor(250, 360 + GFX_Print_Uart_Cursor);
      gfx->setTextSize(1);
      gfx->setTextColor(CYAN);

      gfx->setTextColor(YELLOW);
      gfx->printf("TX-> ");
      gfx->setTextColor(CYAN);
      gfx->printf("ESP32S3 to RS485: %d", Uart_Count);

      GFX_Print_Uart_Cursor += 10;
      if (GFX_Print_Uart_Cursor > 130) {
        GFX_Print_Uart_Cursor = 0;
        gfx->fillRect(230, 330, 280, 150, BLACK);
        gfx->setCursor(265, 340);
        gfx->setTextSize(2);
        gfx->setTextColor(BLUE);
        gfx->printf("UART Information");
      }
#endif

#if defined T_Panel_V1_2_CAN
      gfx->setCursor(250, 360 + GFX_Print_Uart_Cursor);
      gfx->setTextSize(1);
      gfx->setTextColor(CYAN);

      gfx->setTextColor(YELLOW);
      gfx->printf("TX-> ");
      gfx->setTextColor(CYAN);
      gfx->printf("ESP32S3 to CAN: %d", Uart_Count);

      GFX_Print_Uart_Cursor += 10;
      if (GFX_Print_Uart_Cursor > 130) {
        GFX_Print_Uart_Cursor = 0;
        gfx->fillRect(230, 330, 280, 150, BLACK);
        gfx->setCursor(265, 340);
        gfx->setTextSize(2);
        gfx->setTextColor(BLUE);
        gfx->printf("UART Information");
      }
#endif

      cycleInterval = millis() + 2000;

      while (SerialPort1.available() > 0)  // 清除串口1缓存
      {
        SerialPort1.read();
      }

#if defined T_Panel_V1_2_RS485
      while (SerialPort2.available() > 0)  // 清除串口2缓存
      {
        SerialPort2.read();
      }

      gfx->XL_digitalWrite(XL95X5_RS485_CON, HIGH);
      SerialPort2.printf("RS485 port 2: %d", Uart_Count);
      gfx->XL_digitalWrite(XL95X5_RS485_CON, LOW);
#endif

      SerialPort1.print(Uart_Count);
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

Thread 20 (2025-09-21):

LCD screen not clear white, more blue/green

SpaceTeddy, 2025-09-21:
### Operating System

Arduino

### IDE

PlatformIO with LilyGo Demos

### Software Package Version

Arduino over platformio

### Description

Hi, I bought 2 TPanelS3 RS485 version and both seems to have no clear white color on the screen.
White appears more like green/blue mix.
Any recommentations? it is possible to tune some parameters?
thx

### Sketch

```cpp
lvgl.ino
```

### Debug Message

```plain
nr
```

### Other steps to Reproduce

_No response_

SpaceTeddy, 2025-09-21:
found it in my code:
```
//check battery voltage
        int raw_adc = analogRead(BATTERY_ADC_PIN);
        float voltage = (raw_adc * ADC_REF_VOLTAGE / ADC_MAX_VALUE) * VOLTAGE_DIVIDER_RATIO;

caused that trouble :)

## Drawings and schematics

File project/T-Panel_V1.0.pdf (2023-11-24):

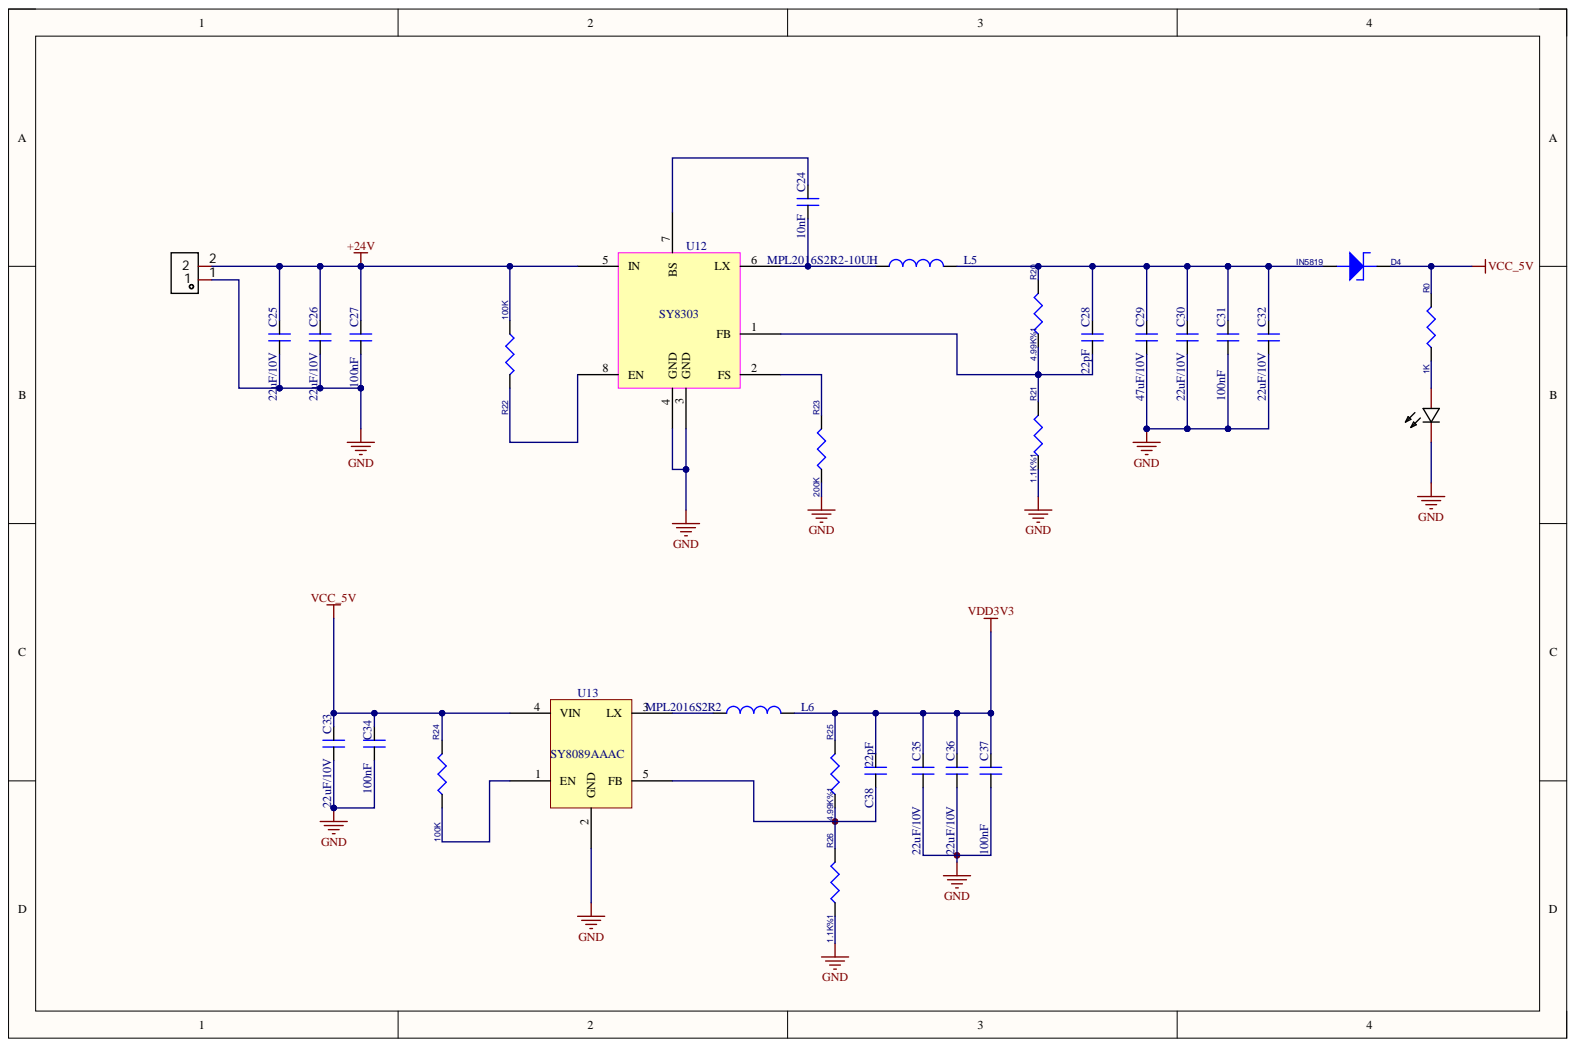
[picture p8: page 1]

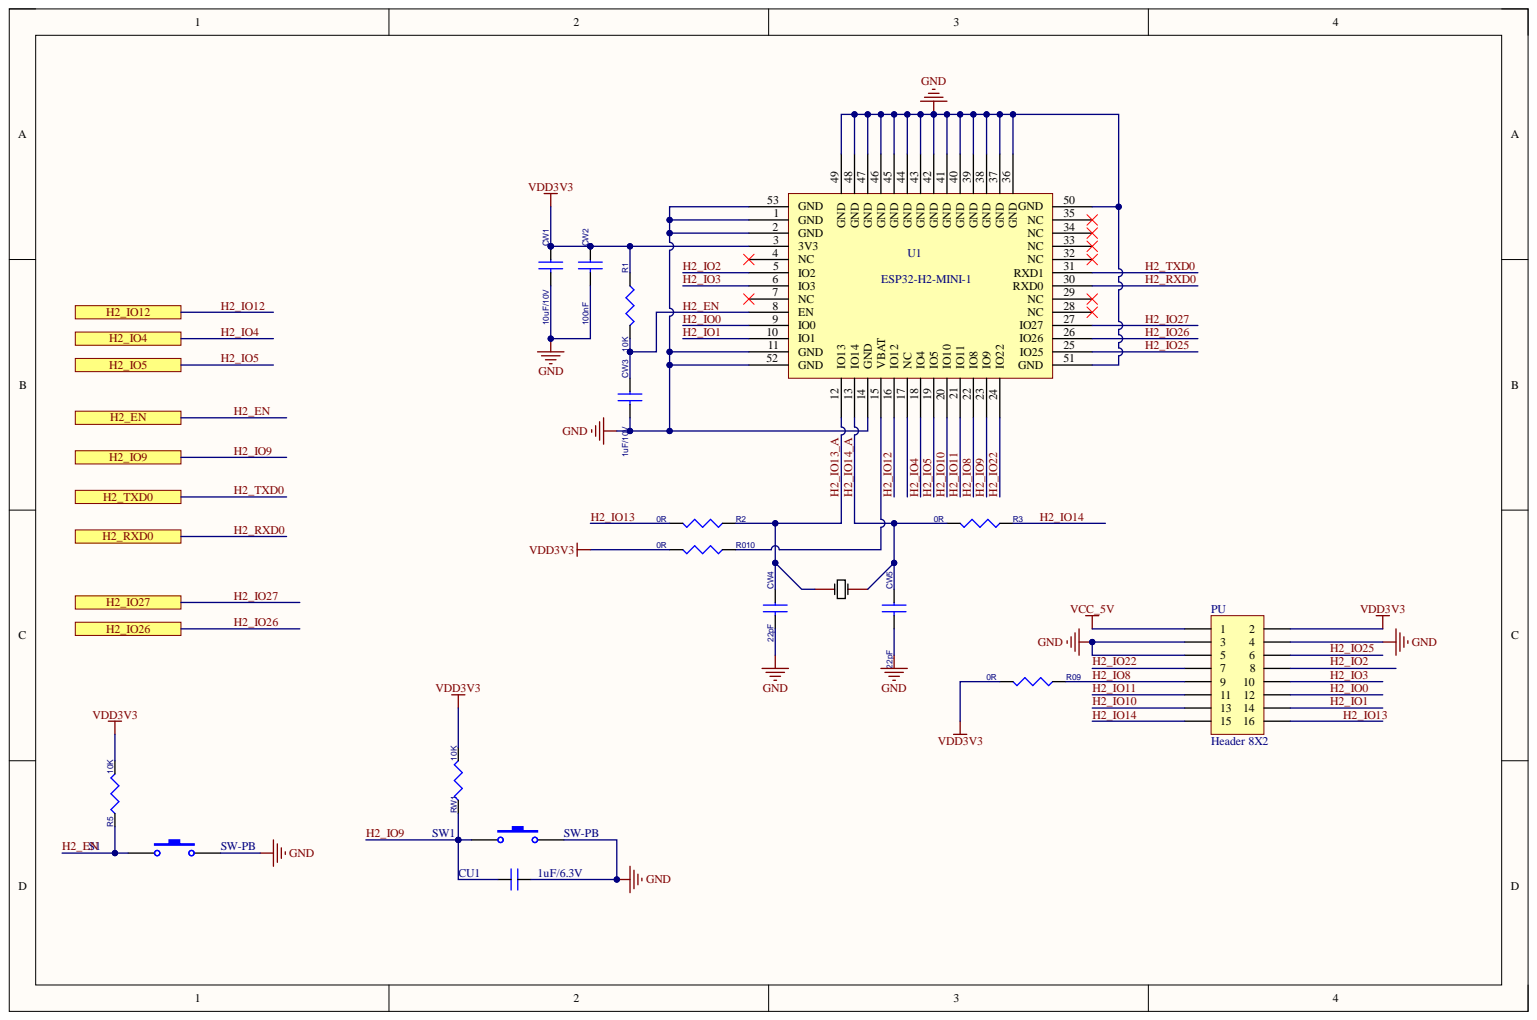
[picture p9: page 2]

GND 36 GND 37 GND 38 GND 39 GND 40 GND 41 GND 42 GND 43 GND 44 GND 45 GND 46 GND 47 GND 48 GND 49

GND 53 U1 ESP32-H2-MINI-1

GND 2

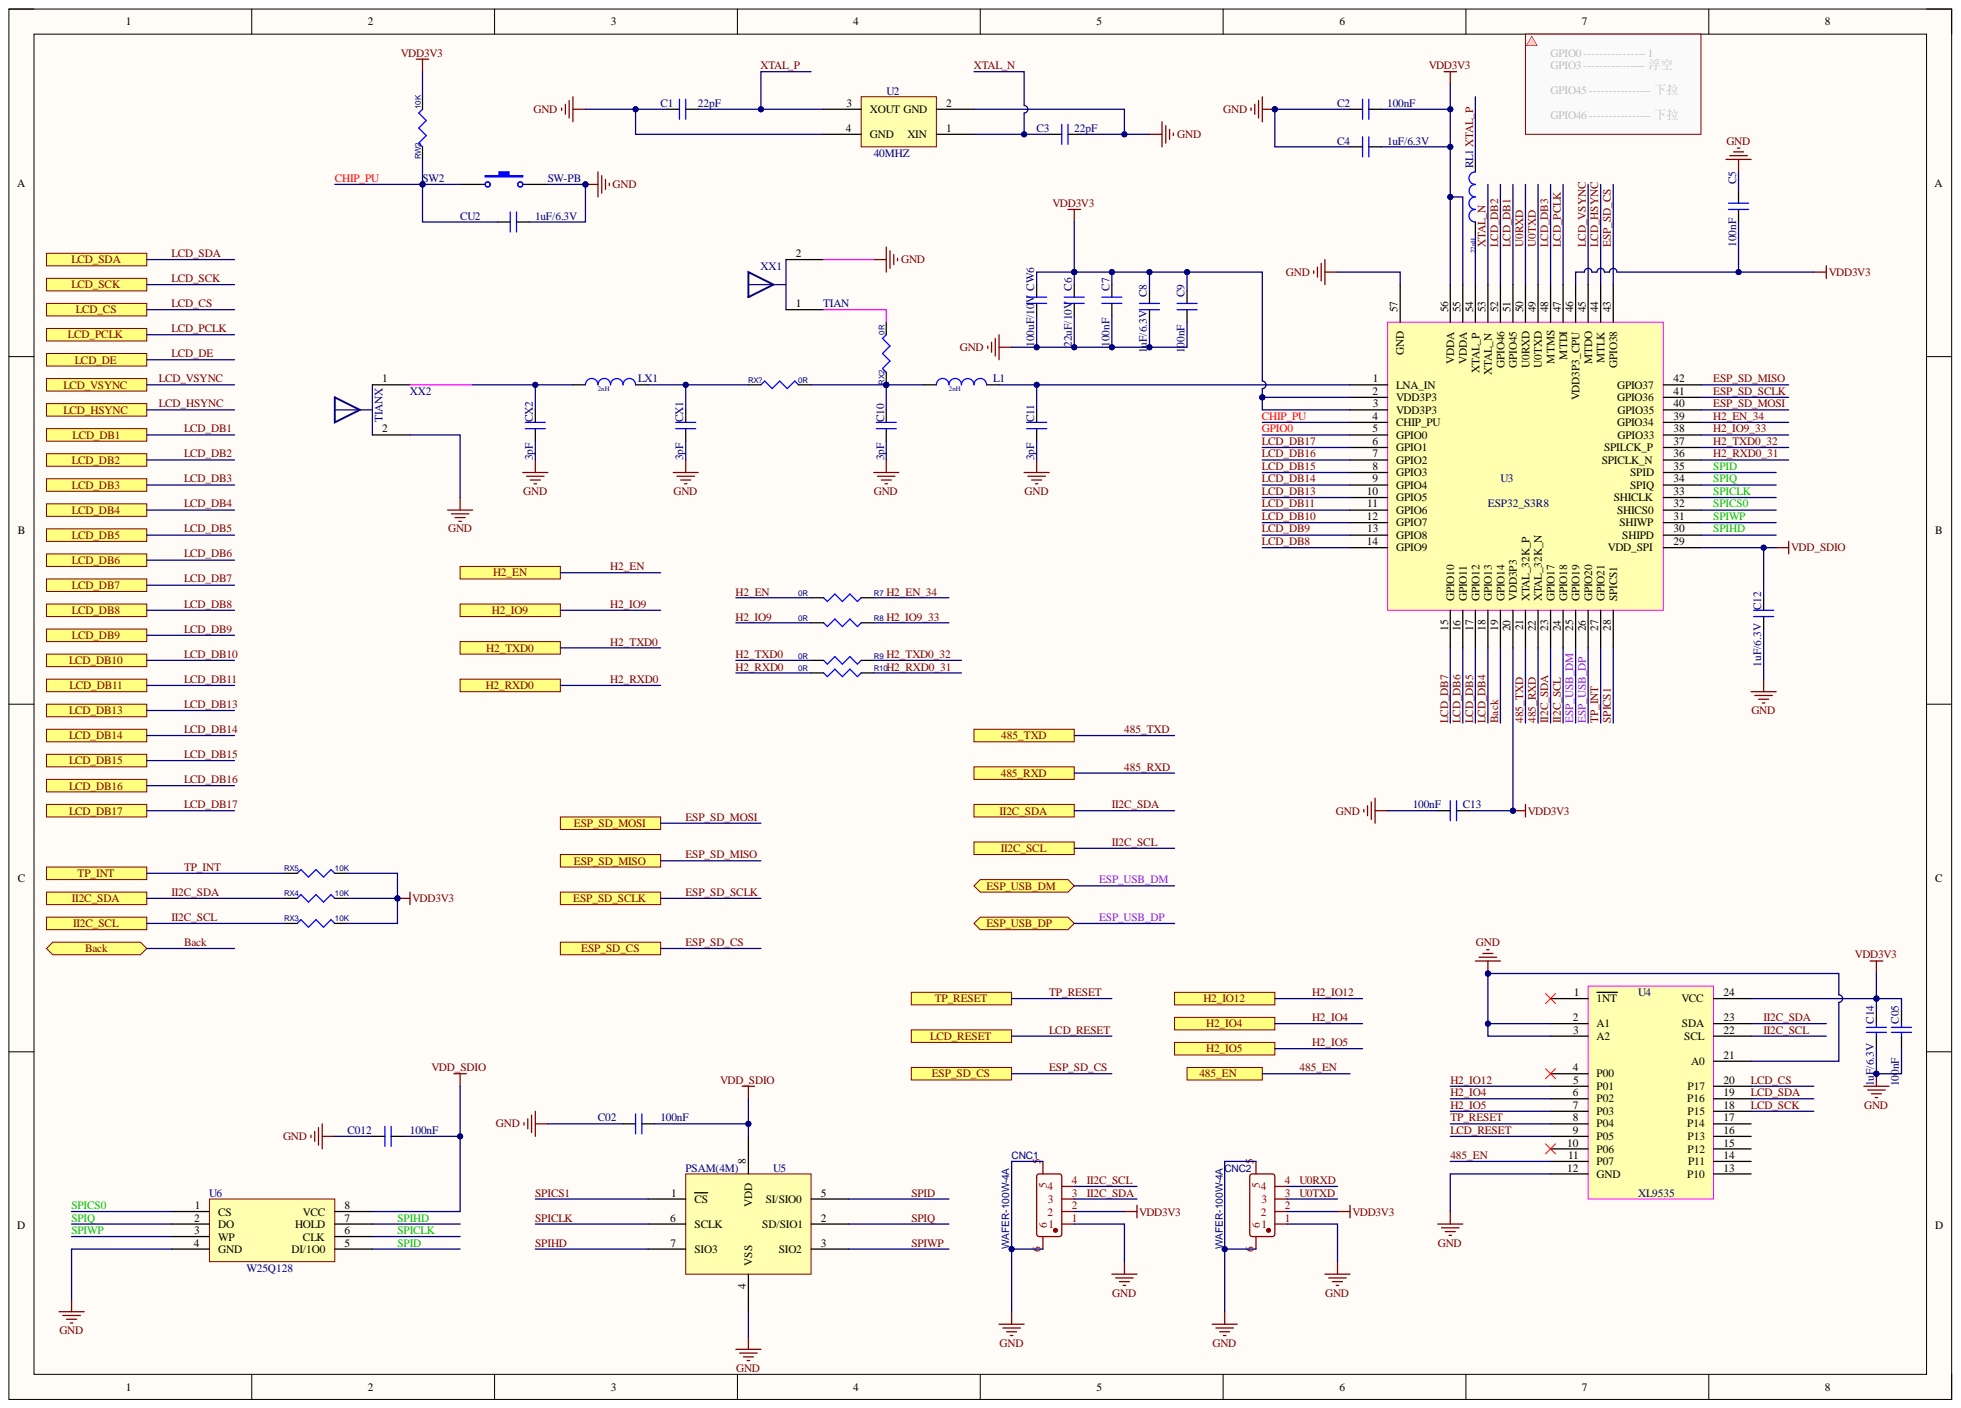
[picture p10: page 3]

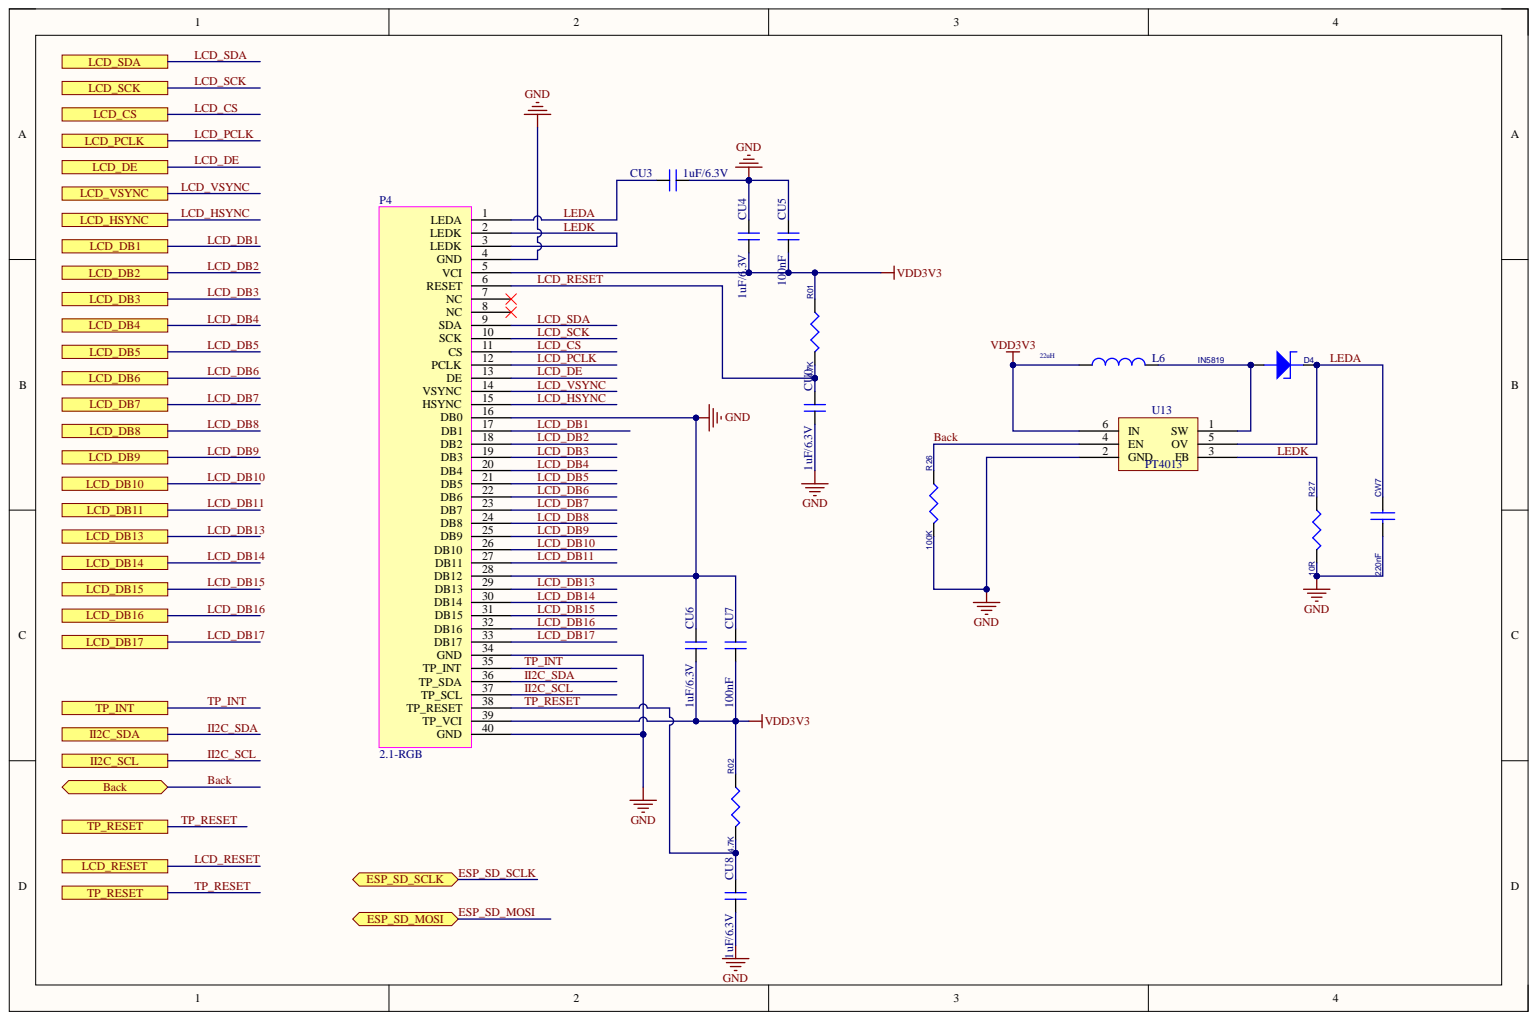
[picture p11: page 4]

6 LCD _RESE T
7 | LCD _SD A

3 9
4 0

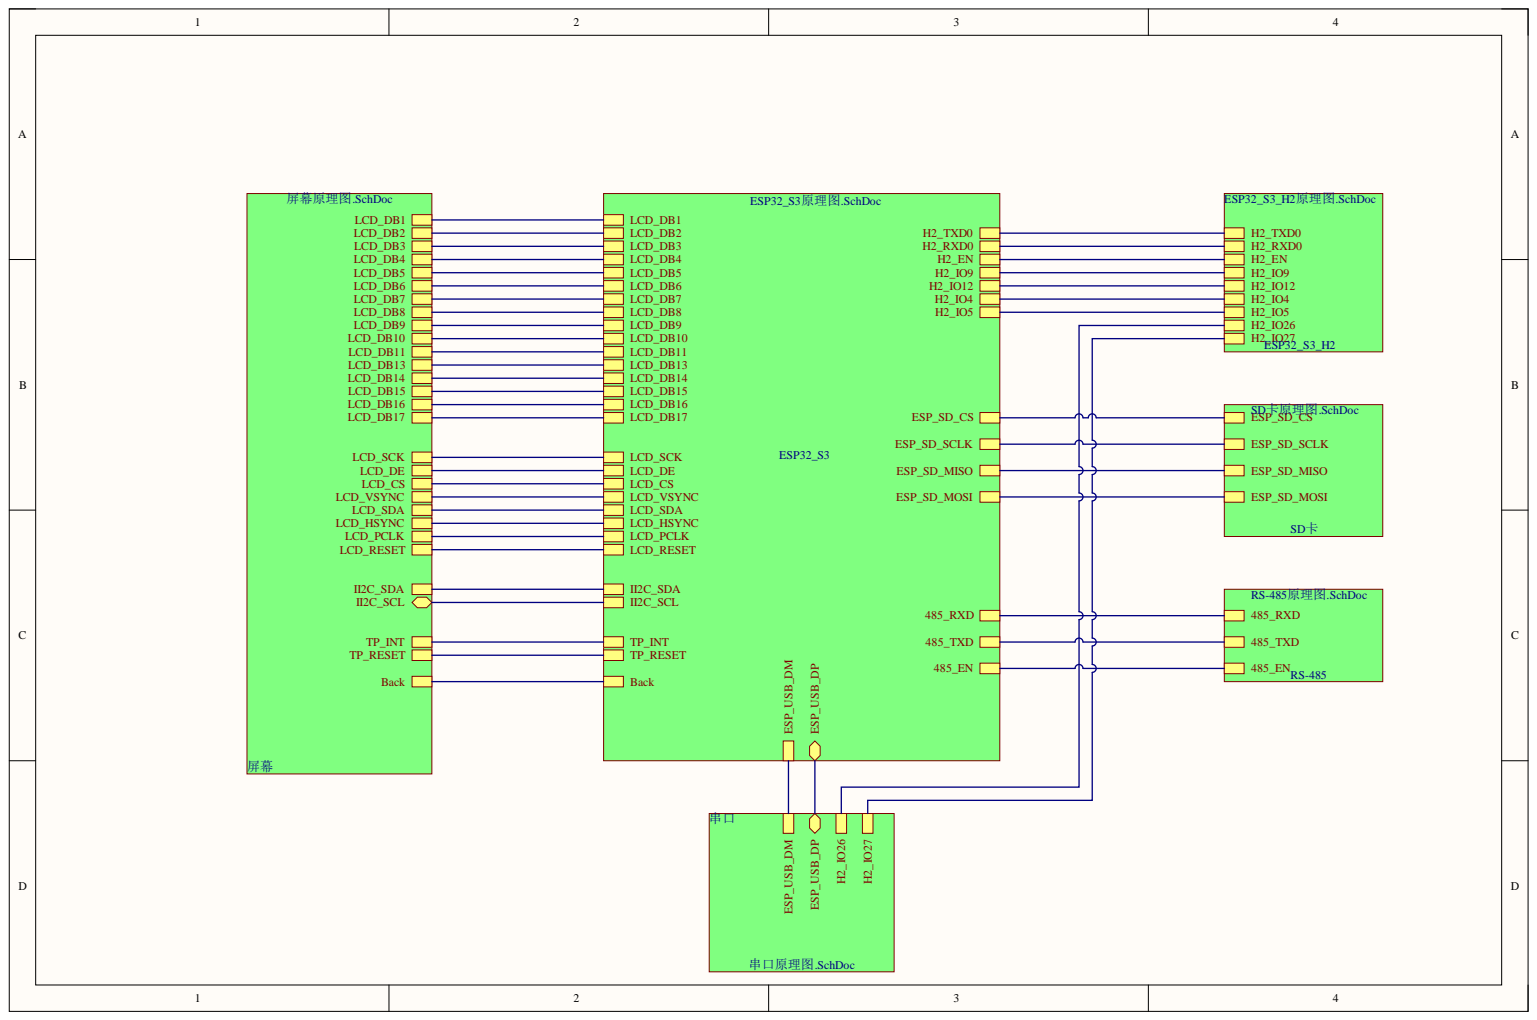
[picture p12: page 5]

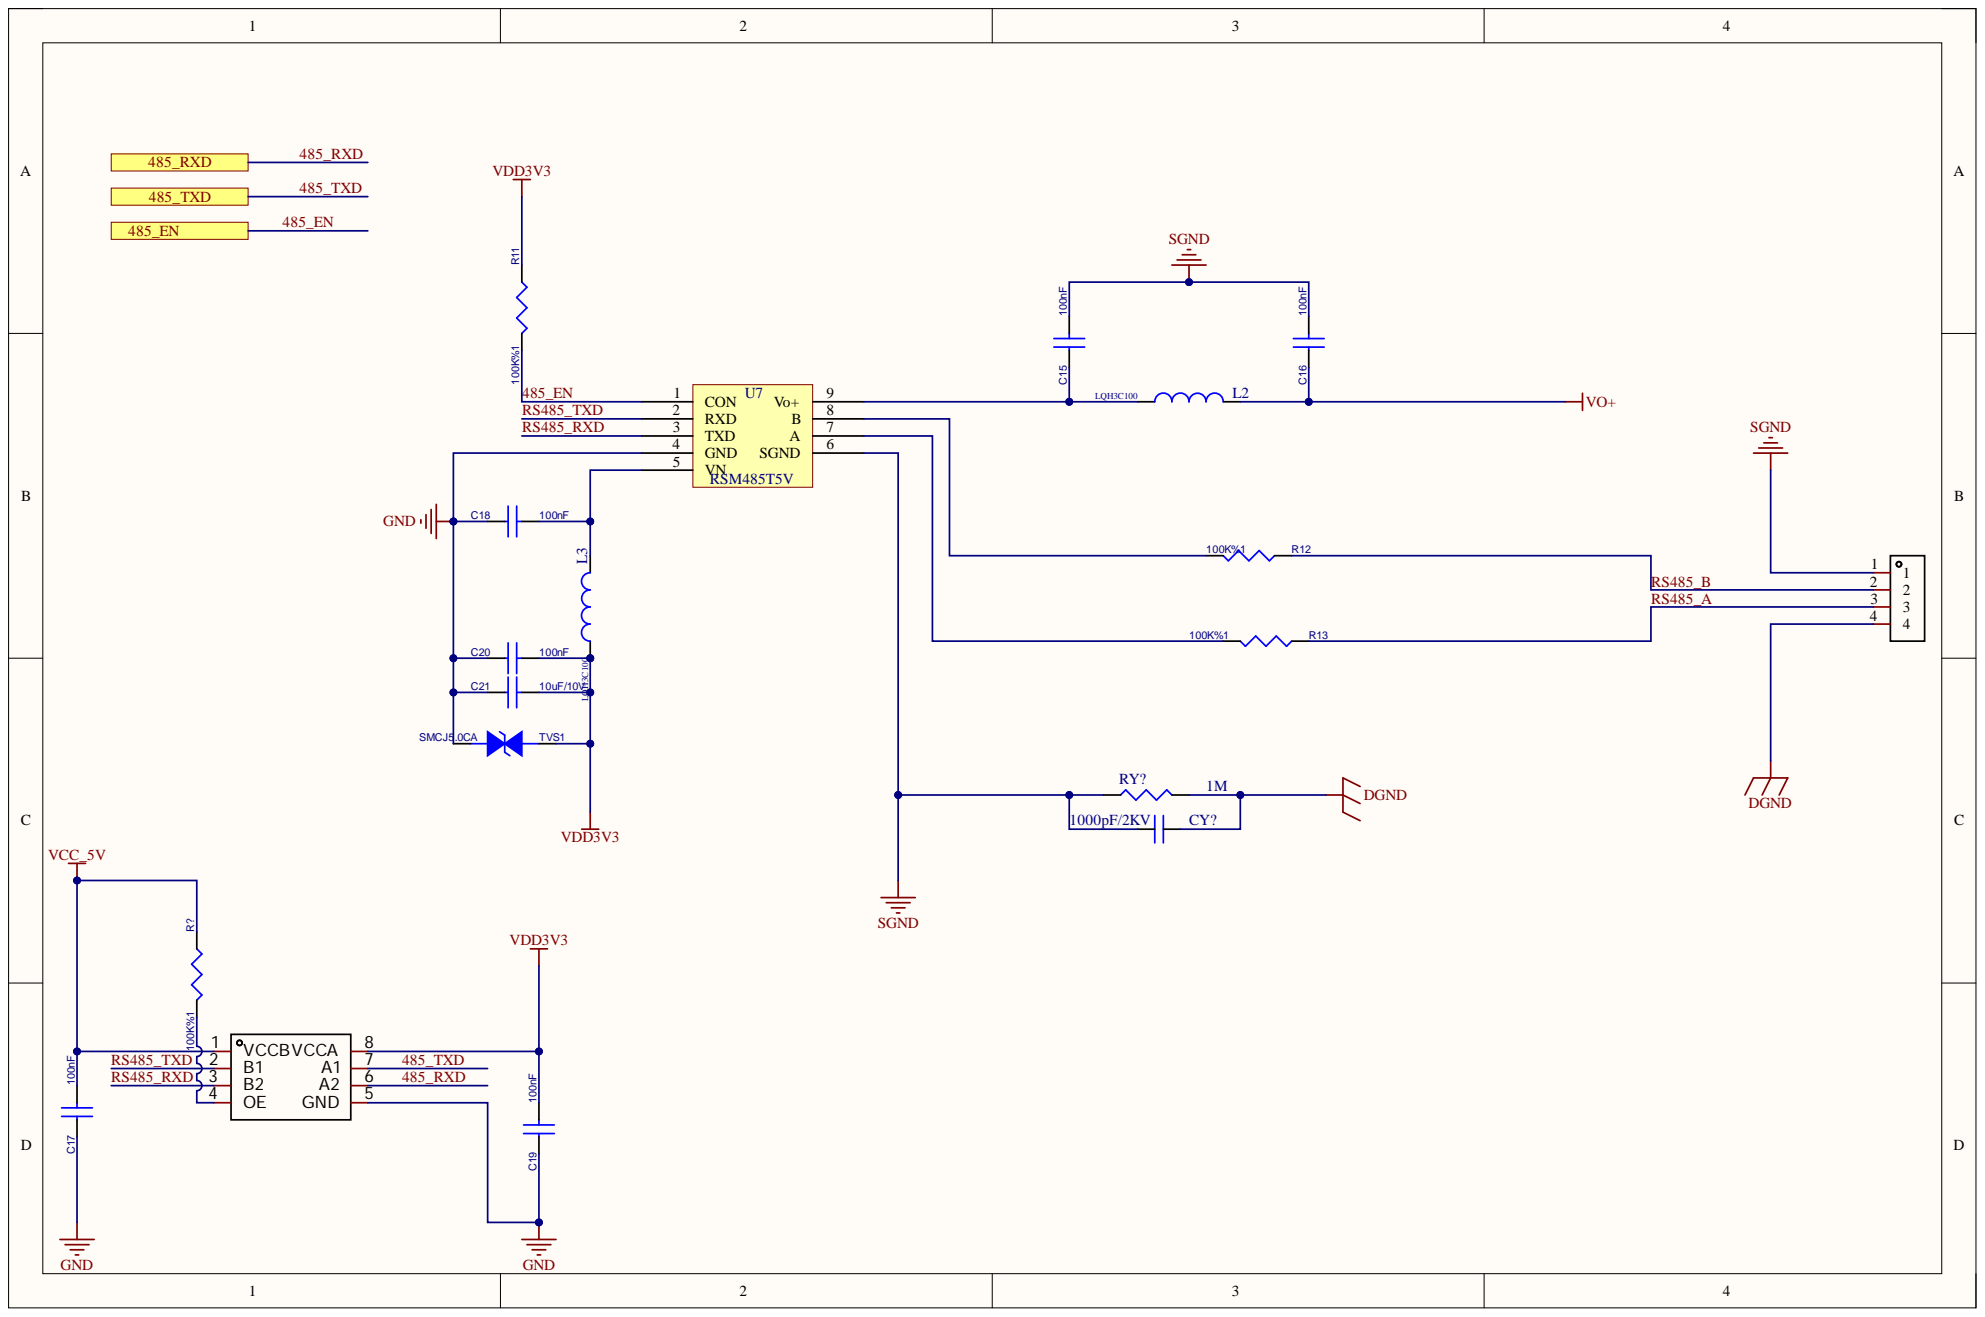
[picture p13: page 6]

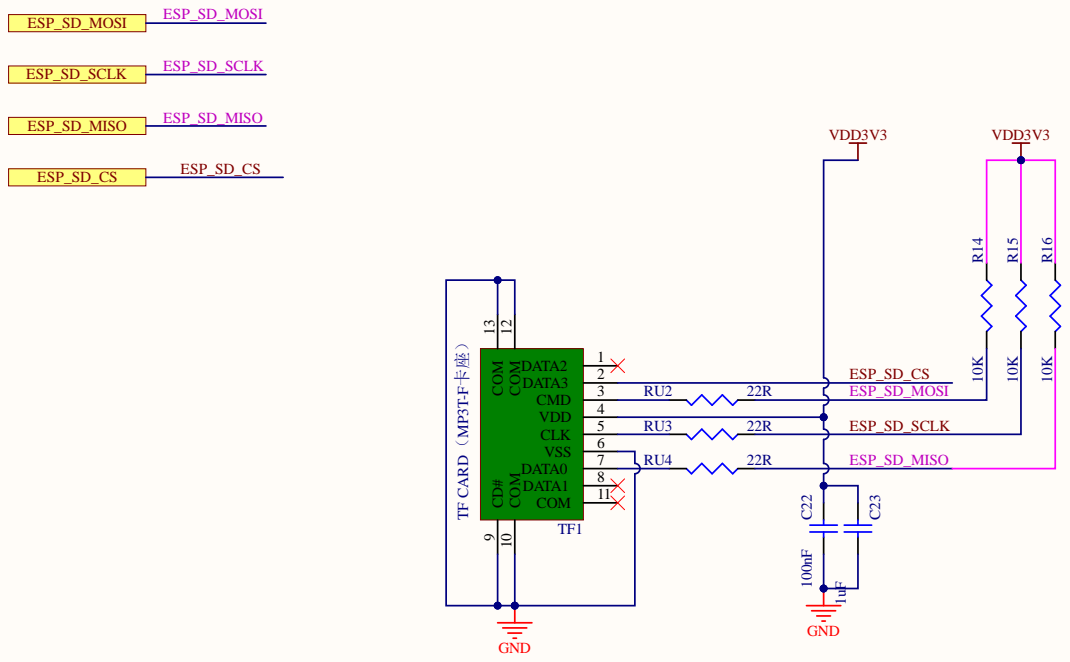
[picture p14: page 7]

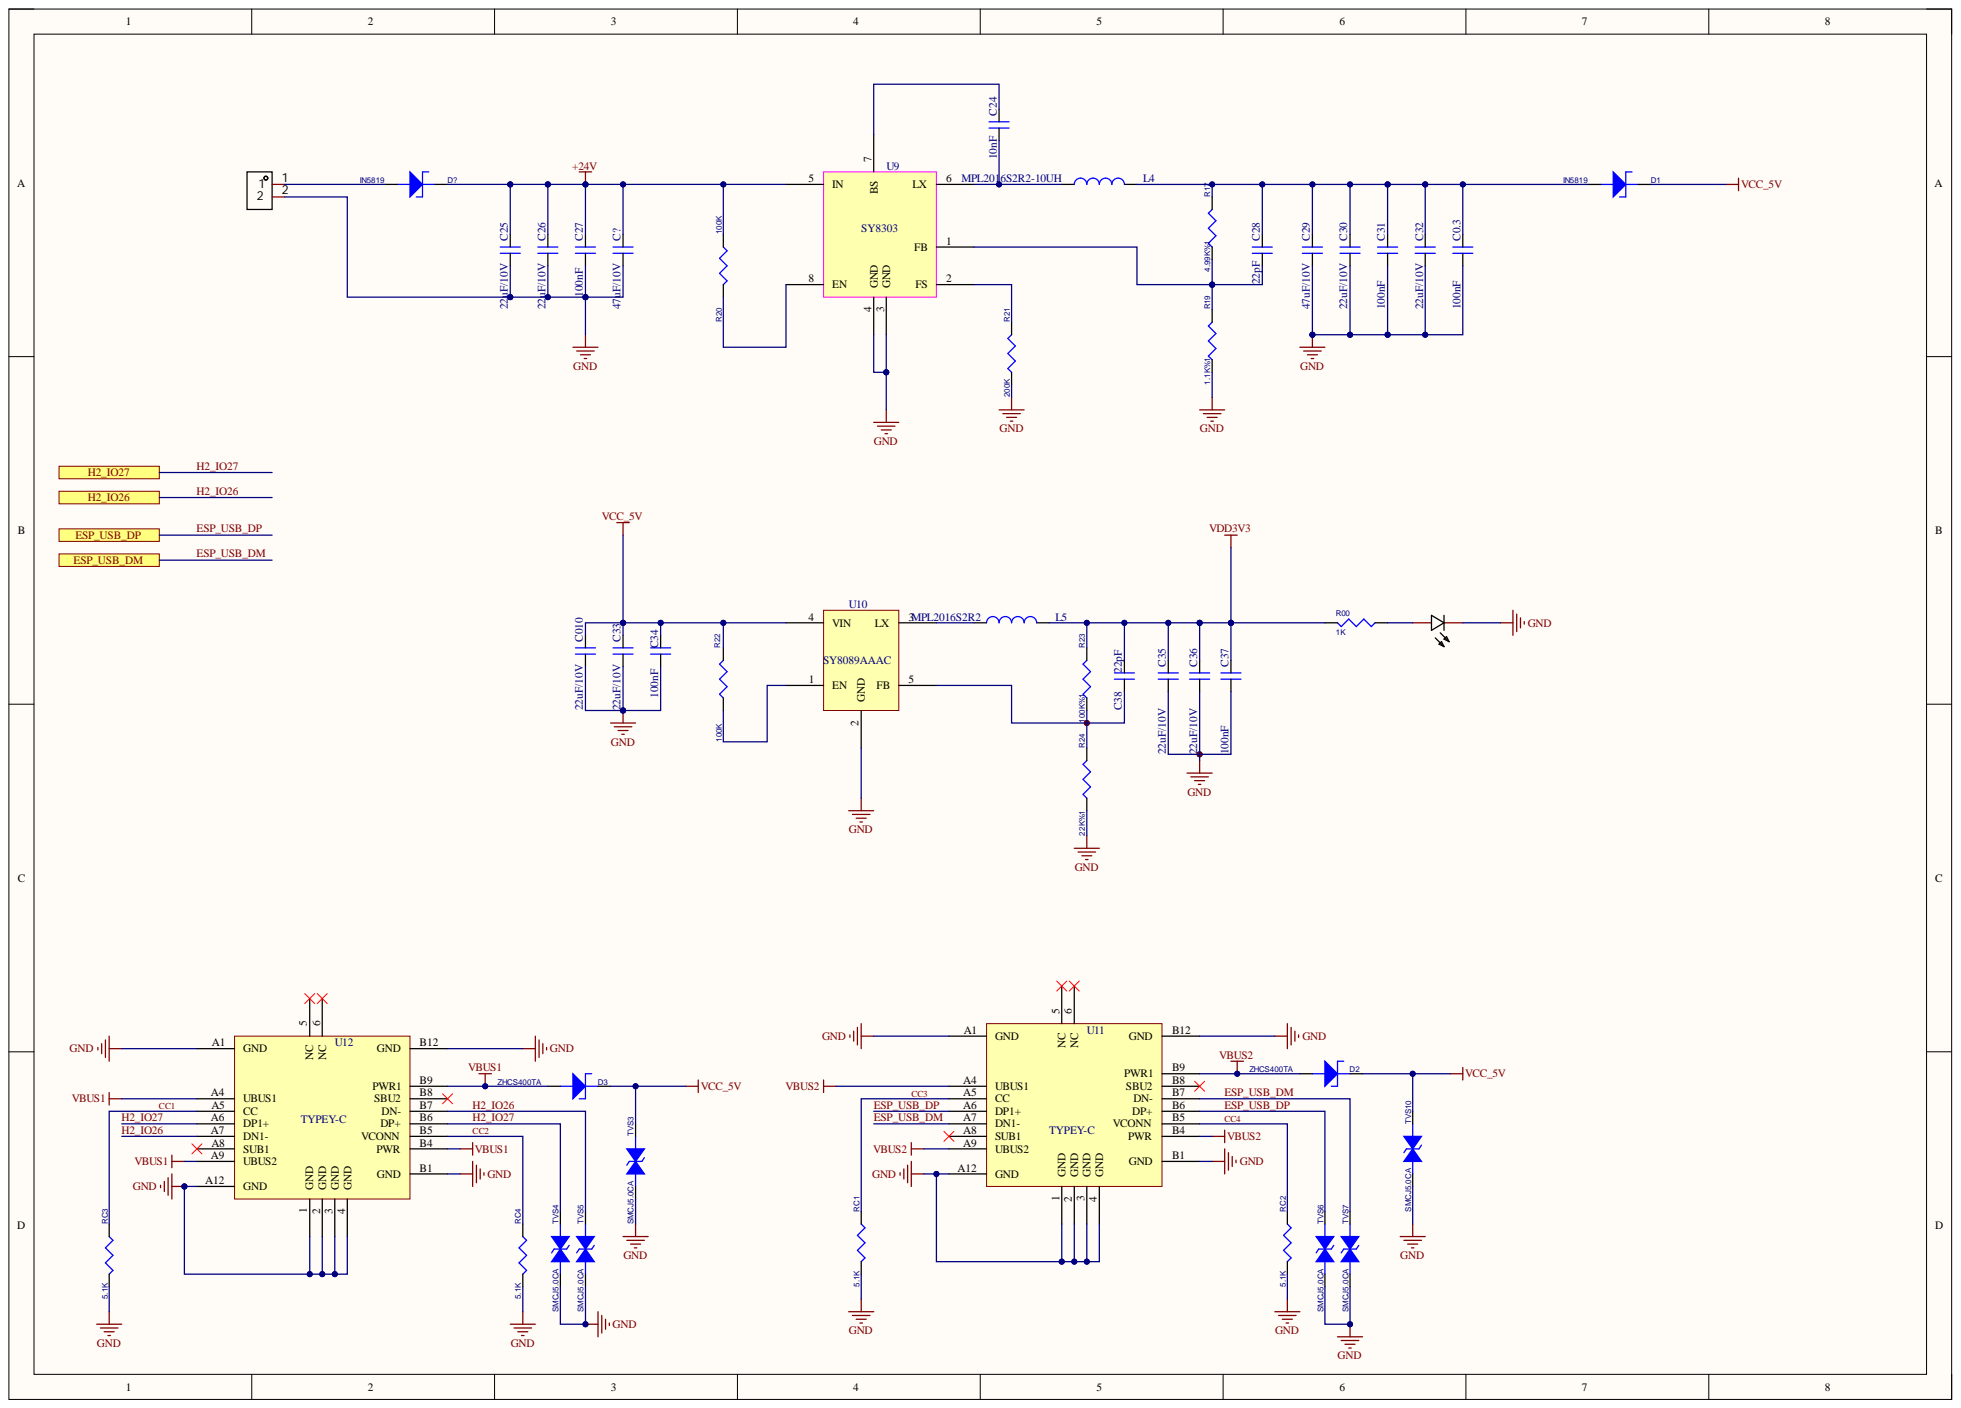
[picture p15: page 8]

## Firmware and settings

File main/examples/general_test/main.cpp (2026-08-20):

/*
 * @Description: Integrated LVGL factory test for T-Panel
 * @Author: LILYGO_L
 * @Date: 2026-05-29
 * @License: GPL 3.0
 */
#include <sys/lock.h>
#include <sys/stat.h>
#include <time.h>
#include <unistd.h>

#include <algorithm>
#include <array>
#include <cstdarg>
#include <cstddef>
#include <cstdint>
#include <cstdio>
#include <cstdlib>
#include <cstring>
#include <memory>
#include <string>
#include <vector>
#include <dirent.h>

#define TOUCH_MODULES_CST_MUTUAL

#include "TouchLib.h"
#include "cpp_bus_driver_library.h"
#include "driver/gpio.h"
#include "driver/i2c_master.h"
#include "driver/sdspi_host.h"
#include "driver/spi_common.h"
#include "driver/uart.h"
#include "esp_attr.h"
#include "esp_err.h"
#include "esp_event.h"
#include "esp_heap_caps.h"
#include "esp_lcd_panel_ops.h"
#include "esp_lcd_panel_rgb.h"
#include "esp_netif.h"
#include "esp_sntp.h"
#include "esp_timer.h"
#include "esp_twai.h"
#include "esp_twai_onchip.h"
#include "esp_vfs_fat.h"
#include "esp_wifi.h"
#include "freertos/FreeRTOS.h"
#include "freertos/queue.h"
#include "freertos/task.h"
#include "draw/sw/lv_draw_sw.h"
#include "lvgl.h"
#include "lvgl_startup_images.h"
#include "nvs_flash.h"
#include "sd_protocol_defs.h"
#include "sdmmc_cmd.h"
#include "st7701_driver.h"
#include "t_panel_config.h"

namespace {

constexpr int kLvglTickPeriodMs = 1;
constexpr int kLvglTaskStackSize = 14 * 1024;
constexpr int kLvglTaskPriority = 2;
constexpr int kLvglRefreshPeriodMs = 20;
constexpr int kLvglTaskMinDelayMs = kLvglRefreshPeriodMs;
constexpr int kLvglTaskMaxDelayMs = 500;
constexpr int kRotationButtonTaskStackSize = 2 * 1024;
constexpr int kRotationButtonTaskPriority = 1;
constexpr int kRotationButtonPollMs = 20;
constexpr int kRotationButtonDebounceMs = 250;
constexpr int kLvglDrawBufferLines = 20;
constexpr int kBacklightFadeTimeMs = 800;
constexpr int kI2cFreqHz = 400000;
constexpr int kBytesPerPixel = 2;

constexpr uart_port_t kRs485UartPort = UART_NUM_2;
constexpr int kRs485BaudRate = 115200;
constexpr int kRs485BufferSize = 4096;
constexpr int kRs485PayloadSize = 240;
constexpr uint8_t kRs485Header0 = 0xAA;
constexpr uint8_t kRs485Header1 = 0x55;
constexpr size_t kRs485HeaderSize = 2;
constexpr size_t kRs485SequenceSize = 4;
constexpr size_t kRs485LengthSize = 2;
constexpr size_t kRs485CrcSize = 2;
constexpr size_t kRs485PacketOverhead = kRs485HeaderSize + kRs485SequenceSize +
                                        kRs485LengthSize + kRs485CrcSize;
constexpr size_t kRs485PacketSize = kRs485PacketOverhead + kRs485PayloadSize;
constexpr int kRs485TxDoneTimeoutMs = 200;
constexpr char kRs485TestChar = 'R';

constexpr int kCanDataLength = 8;
constexpr int kCanTxWaitMs = 0;
constexpr int kCanTxIntervalMs = 20;
constexpr int kCanRecoverRetryIntervalMs = 1000;
constexpr int kCanPollMs = 100;
constexpr int kCanMaxReceiveFramesPerLoop = 32;
constexpr uint32_t kCanTestId = 0x0F1;
constexpr char kCanTestChar = 'C';
constexpr int kCanBitrate = 1000000;
constexpr int kCanTxQueueDepth = 16;
constexpr int kCanRxQueueDepth = 32;

constexpr int kTestPrintIntervalMs = 1000;
constexpr int kWifiConnectTimeoutMs = 10000;
constexpr char kWifiSsid[] = "LilyGo-AABB";
constexpr char kWifiPassword[] = "xinyuandianzi";
constexpr int kBlePairTimeoutMs = 20000;
constexpr int kBlePollMs = 500;
constexpr int kBleSuccessHoldMs = 2000;
constexpr int kSdTaskStackSize = 8 * 1024;
constexpr int kSdTaskPriority = 1;
constexpr int kSdSpiMaxFreqKhz = 10000;
constexpr int kMaxSdTreeDepth = 4;
constexpr int kMaxSdTreeEntries = 32;
constexpr char kSdMountPoint[] = "/sdcard";
constexpr int kPageCount = 6;
constexpr int kDotHitSize = 42;
constexpr int kDotGap = 4;
constexpr int kDotRowWidth = kDotHitSize * kPageCount + kDotGap * (kPageCount - 1);
constexpr int kIndicatorHeight = 72;
constexpr int kPageWidth = t_panel::device::st7701::kWidth;
constexpr int kPageHeight = t_panel::device::st7701::kHeight;
constexpr int kCardWidth = 410;
constexpr int kCardHeight = 330;
constexpr int kPrimaryStatusPanelHeight = 190;
constexpr int kTouchStatusPanelHeight = 250;
constexpr int kBusStatusPanelHeight = 96;
constexpr int kDisplayTestEnterPixelClockHz = 11000000;
constexpr uint32_t kColorWindow = 0xF4F6FB;
constexpr uint32_t kColorSurface = 0xFFFBFE;
constexpr uint32_t kColorSurfaceContainer = 0xF0F3FA;
constexpr uint32_t kColorSurfaceContainerHigh = 0xE9EDF5;
constexpr uint32_t kColorPrimary = 0x2F6BFF;
constexpr uint32_t kColorPrimaryPressed = 0x1D56D6;
constexpr uint32_t kColorPrimaryContainer = 0xDCE7FF;
constexpr uint32_t kColorOnSurface = 0x1D1B20;
constexpr uint32_t kColorOnSurfaceVariant = 0x5E6470;
constexpr uint32_t kColorOutline = 0xD6DAE3;

enum class Page : int {
  kDisplay = 0,
  kTouch,
  kWifiTime,
  kRs485Can,
  kSd,
  kBle,
};

enum class LinkMode {
  kIdle,
  kRs485Send,
  kRs485Receive,
  kCanSend,
  kCanReceive,
};

struct CanRxFrame {
  uint32_t id;
  uint8_t data[kCanDataLength];
  uint8_t data_length;
  bool is_remote;
  bool is_extended;
};

enum class BleState {
  kIdle,
  kWaiting,
  kPassed,
  kFailed,
};

_lock_t g_lvgl_api_lock;

std::shared_ptr<cpp_bus_driver::HardwareI2c1> g_i2c_bus;
std::unique_ptr<cpp_bus_driver::Xl95x5> g_xl9535;
std::unique_ptr<cpp_bus_driver::HardwareI2c1> g_touch_i2c;
TouchLib g_touch;

lv_display_t* g_display = nullptr;
esp_lcd_panel_handle_t g_panel_handle = nullptr;
lv_obj_t* g_root = nullptr;
lv_obj_t* g_tileview = nullptr;
lv_obj_t* g_tiles[kPageCount] = {};
lv_obj_t* g_page_dots[kPageCount] = {};
lv_obj_t* g_page_name_label = nullptr;
lv_obj_t* g_display_label = nullptr;
lv_obj_t* g_fullscreen_display = nullptr;
lv_obj_t* g_touch_status = nullptr;
lv_obj_t* g_wifi_status = nullptr;
lv_obj_t* g_link_status = nullptr;
lv_obj_t* g_sd_status = nullptr;
lv_obj_t* g_ble_status = nullptr;

Page g_active_page = Page::kDisplay;
int g_display_pattern = 0;
bool g_wifi_ready = false;
bool g_wifi_started = false;
TaskHandle_t g_wifi_task_handle = nullptr;
TaskHandle_t g_link_task_handle = nullptr;
volatile bool g_link_stop = false;
LinkMode g_link_mode = LinkMode::kIdle;
bool g_sd_spi_bus_ready = false;
bool g_sd_mounted = false;
sdmmc_card_t* g_sd_card = nullptr;
TaskHandle_t g_sd_task_handle = nullptr;
TaskHandle_t g_ble_task_handle = nullptr;
BleState g_ble_state = BleState::kIdle;
lv_point_t g_touch_last = {};
volatile bool g_touch_int_flag = false;
lv_display_rotation_t g_display_rotation = LV_DISPLAY_ROTATION_180;
void* g_rotated_flush_buffer = nullptr;
size_t g_rotated_flush_buffer_size = 0;
std::vector<uint8_t> g_rs485_rx_stream;
uint32_t g_rs485_tx_sequence = 0;
uint32_t g_rs485_expected_sequence = 0;
bool g_rs485_has_expected_sequence = false;
twai_node_handle_t g_can_node = nullptr;
QueueHandle_t g_can_rx_queue = nullptr;
volatile uint32_t g_can_error_flags = 0;
volatile twai_error_state_t g_can_state = TWAI_ERROR_ACTIVE;
volatile bool g_can_recovering = false;
int64_t g_can_last_recover_us = 0;

const lv_image_dsc_t* const kWallpaperTable[] = {
    &kLvglStartupImage1,
    &kLvglStartupImage2,
    &kLvglStartupImage3,
};

void SetLabel(lv_obj_t* label, const std::string& text) {
  printf("%s\n", text.c_str());
  _lock_acquire(&g_lvgl_api_lock);
  if (label != nullptr) {
    lv_label_set_text(label, text.c_str());
  }
  _lock_release(&g_lvgl_api_lock);
}

void SetLabelUnlocked(lv_obj_t* label, const char* text) {
  printf("%s\n", text);
  if (label != nullptr) {
    lv_label_set_text(label, text);
  }
}

void SetLabelFmt(lv_obj_t* label, const char* fmt, ...) {
  char buffer[512] = {};
  va_list args;
  va_start(args, fmt);
  std::vsnprintf(buffer, sizeof(buffer), fmt, args);
  va_end(args);
  SetLabel(label, buffer);
}

bool InitXl9535() {
  g_i2c_bus = std::make_shared<cpp_bus_driver::HardwareI2c1>(
      t_panel::gpio::i2c::kSda, t_panel::gpio::i2c::kScl, I2C_NUM_0);
  g_xl9535 = std::make_unique<cpp_bus_driver::Xl95x5>(
      g_i2c_bus, t_panel::device::xl95x5::kI2cAddress);

  if (!g_xl9535->Init(kI2cFreqHz)) {
    printf("Init XL9535 failed\n");
    return false;
  }
  return true;
}

int TouchI2cRead(
    uint8_t dev_addr, uint16_t reg_addr, uint8_t* data, uint8_t len) {
  if (g_touch_i2c == nullptr || data == nullptr) {
    return -1;
  }

  uint8_t reg_buffer[2] = {};
  size_t reg_size = 1;
  if (reg_addr > 0xFF) {
    reg_buffer[0] = static_cast<uint8_t>(reg_addr >> 8);
    reg_buffer[1] = static_cast<uint8_t>(reg_addr & 0xFF);
    reg_size = 2;
  } else {
    reg_buffer[0] = static_cast<uint8_t>(reg_addr);
  }

  return g_touch_i2c->WriteRead(reg_buffer, reg_size, data, len) ? 0 : -1;
}

int TouchI2cWrite(
    uint8_t dev_addr, uint16_t reg_addr, uint8_t* data, uint8_t len) {
  if (g_touch_i2c == nullptr) {
    return -1;
  }

  uint8_t write_buffer[34] = {};
  size_t write_size = 1;
  if (reg_addr > 0xFF) {
    if (len + 2 > sizeof(write_buffer)) {
      return -1;
    }
    write_buffer[0] = static_cast<uint8_t>(reg_addr >> 8);
    write_buffer[1] = static_cast<uint8_t>(reg_addr & 0xFF);
    write_size = 2;
  } else {
    if (len + 1 > sizeof(write_buffer)) {
      return -1;
    }
    write_buffer[0] = static_cast<uint8_t>(reg_addr);
  }

  if (len > 0 && data != nullptr) {
    std::copy(data, data + len, write_buffer + write_size);
  }
  write_size += len;
  return g_touch_i2c->Write(write_buffer, write_size) ? 0 : -1;
}

bool InitTouch() {
  using Xl95x5Mode = cpp_bus_driver::Xl95x5::Mode;

  if (!g_xl9535->SetGpioMode(
          t_panel::gpio::xl95x5::kTouchRst, Xl95x5Mode::kOutput)) {
    printf("Set touch reset mode failed\n");
    return false;
  }
  g_xl9535->GpioWrite(t_panel::gpio::xl95x5::kTouchRst, 0);
  vTaskDelay(pdMS_TO_TICKS(200));
  g_xl9535->GpioWrite(t_panel::gpio::xl95x5::kTouchRst, 1);
  vTaskDelay(pdMS_TO_TICKS(200));

  g_touch_i2c = std::make_unique<cpp_bus_driver::HardwareI2c1>(g_i2c_bus);
  if (!g_touch_i2c->Init(kI2cFreqHz, t_panel::device::cst3240::kI2cAddress)) {
    printf("Init touch I2C failed\n");
    return false;
  }
  if (!g_touch.begin(t_panel::device::cst3240::kI2cAddress, -1, TouchI2cRead,
          TouchI2cWrite)) {
    printf("Init TouchLib failed\n");
    return false;
  }

  printf("Init CST3240 touch done\n");
  return true;
}

void IRAM_ATTR TouchInterruptHandler(void* arg) {
  g_touch_int_flag = true;
}

bool InitTouchInterrupt() {
  gpio_config_t io_config = {};
  io_config.pin_bit_mask = 1ULL << t_panel::gpio::cst3240::kInt;
  io_config.mode = GPIO_MODE_INPUT;
  io_config.pull_up_en = GPIO_PULLUP_ENABLE;
  io_config.pull_down_en = GPIO_PULLDOWN_DISABLE;
  io_config.intr_type = GPIO_INTR_NEGEDGE;
  esp_err_t err = gpio_config(&io_config);
  if (err != ESP_OK) {
    printf("Config touch interrupt failed: %s\n", esp_err_to_name(err));
    return false;
  }

  err = gpio_install_isr_service(0);
  if (err != ESP_OK && err != ESP_ERR_INVALID_STATE) {
    printf("Install GPIO ISR service failed: %s\n", esp_err_to_name(err));
    return false;
  }

  err = gpio_isr_handler_add(
      static_cast<gpio_num_t>(t_panel::gpio::cst3240::kInt),
      TouchInterruptHandler, nullptr);
  if (err != ESP_OK && err != ESP_ERR_INVALID_STATE) {
    printf("Add touch interrupt handler failed: %s\n", esp_err_to_name(err));
    return false;
  }
  err = gpio_intr_enable(static_cast<gpio_num_t>(t_panel::gpio::cst3240::kInt));
  if (err != ESP_OK) {
    printf("Enable touch interrupt failed: %s\n", esp_err_to_name(err));
    return false;
  }

  g_touch_int_flag = false;
  return true;
}

bool NotifyLvglFlushReady(esp_lcd_panel_handle_t panel,
    const esp_lcd_rgb_panel_event_data_t* event_data, void* user_ctx) {
  lv_display_t* display = static_cast<lv_display_t*>(user_ctx);
  lv_display_flush_ready(display);
  return false;
}

void LvglFlush(lv_display_t* display, const lv_area_t* area, uint8_t* px_map) {
  esp_lcd_panel_handle_t panel_handle =
      static_cast<esp_lcd_panel_handle_t>(lv_display_get_user_data(display));

  const lv_area_t* draw_area = area;
  uint8_t* draw_map = px_map;
  lv_area_t rotated_area = {};
  const lv_display_rotation_t rotation = lv_display_get_rotation(display);

  if (rotation != LV_DISPLAY_ROTATION_0) {
    const int32_t src_width = lv_area_get_width(area);
    const int32_t src_height = lv_area_get_height(area);
    const uint32_t src_stride =
        lv_draw_buf_width_to_stride(src_width, LV_COLOR_FORMAT_RGB565);

    rotated_area = *area;
    lv_display_rotate_area(display, &rotated_area);

    const uint32_t dest_stride = lv_draw_buf_width_to_stride(
        lv_area_get_width(&rotated_area), LV_COLOR_FORMAT_RGB565);
    const size_t rotated_size =
        dest_stride * static_cast<size_t>(lv_area_get_height(&rotated_area));

    if (g_rotated_flush_buffer_size < rotated_size) {
      if (g_rotated_flush_buffer != nullptr) {
        heap_caps_free(g_rotated_flush_buffer);
      }
      g_rotated_flush_buffer =
          heap_caps_malloc(rotated_size, MALLOC_CAP_INTERNAL | MALLOC_CAP_DMA);
      g_rotated_flush_buffer_size =
          g_rotated_flush_buffer != nullptr ? rotated_size : 0;
    }

    if (g_rotated_flush_buffer == nullptr) {
      printf("Allocate rotated LVGL flush buffer failed\n");
      lv_display_flush_ready(display);
      return;
    }

    lv_draw_sw_rotate(px_map, g_rotated_flush_buffer, src_width, src_height,
        src_stride, dest_stride, rotation, LV_COLOR_FORMAT_RGB565);
    draw_area = &rotated_area;
    draw_map = static_cast<uint8_t*>(g_rotated_flush_buffer);
  }

  if (esp_lcd_panel_draw_bitmap(panel_handle, draw_area->x1, draw_area->y1,
          draw_area->x2 + 1, draw_area->y2 + 1, draw_map) != ESP_OK) {
    printf("LVGL flush failed\n");
    lv_display_flush_ready(display);
  }
}

void IncreaseLvglTick(void* arg) { lv_tick_inc(kLvglTickPeriodMs); }

const char* RotationName(lv_display_rotation_t rotation) {
  switch (rotation) {
    case LV_DISPLAY_ROTATION_0:
      return "0";
    case LV_DISPLAY_ROTATION_90:
      return "90";
    case LV_DISPLAY_ROTATION_180:
      return "180";
    case LV_DISPLAY_ROTATION_270:
      return "270";
    default:
      return "?";
  }
}

lv_display_rotation_t NextClockwiseRotation(lv_display_rotation_t rotation) {
  switch (rotation) {
    case LV_DISPLAY_ROTATION_0:
      return LV_DISPLAY_ROTATION_90;
    case LV_DISPLAY_ROTATION_90:
      return LV_DISPLAY_ROTATION_180;
    case LV_DISPLAY_ROTATION_180:
      return LV_DISPLAY_ROTATION_270;
    case LV_DISPLAY_ROTATION_270:
    default:
      return LV_DISPLAY_ROTATION_0;
  }
}

void ApplyDisplayRotation(lv_display_rotation_t rotation) {
  g_display_rotation = rotation;
  _lock_acquire(&g_lvgl_api_lock);
  if (g_display != nullptr) {
    lv_display_set_rotation(g_display, rotation);
    lv_obj_invalidate(lv_display_get_screen_active(g_display));
  }
  _lock_release(&g_lvgl_api_lock);
  printf("LVGL display rotation set to %s degrees\n", RotationName(rotation));
}

bool InitRotationButton() {
  gpio_config_t io_config = {};
  io_config.pin_bit_mask = 1ULL << t_panel::gpio::esp32s3::kBoot;
  io_config.mode = GPIO_MODE_INPUT;
  io_config.pull_up_en = GPIO_PULLUP_ENABLE;
  io_config.pull_down_en = GPIO_PULLDOWN_DISABLE;
  io_config.intr_type = GPIO_INTR_DISABLE;

  const esp_err_t err = gpio_config(&io_config);
  if (err != ESP_OK) {
    printf("Init ESP32-S3 BOOT button failed: %s\n", esp_err_to_name(err));
    return false;
  }
  return true;
}

void RotationButtonTask(void* arg) {
  bool last_pressed =
      gpio_get_level(static_cast<gpio_num_t>(t_panel::gpio::esp32s3::kBoot)) ==
      0;
  TickType_t last_trigger_tick = 0;

  while (true) {
    const bool pressed =
        gpio_get_level(static_cast<gpio_num_t>(t_panel::gpio::esp32s3::kBoot)) ==
        0;
    const TickType_t now = xTaskGetTickCount();

    if (pressed && !last_pressed &&
        now - last_trigger_tick >= pdMS_TO_TICKS(kRotationButtonDebounceMs)) {
      last_trigger_tick = now;
      ApplyDisplayRotation(NextClockwiseRotation(g_display_rotation));
    }

    last_pressed = pressed;
    vTaskDelay(pdMS_TO_TICKS(kRotationButtonPollMs));
  }
}

void UpdateTouchStatusUnlocked(
    const TP_Point& point, uint8_t point_count, bool pressed) {
  if (g_touch_status == nullptr) {
    return;
  }

  char buffer[192] = {};
  std::snprintf(buffer, sizeof(buffer),
      "Touch: %s\nPoints: %u\nX: %d\nY: %d\nPressure: %d\nState: %u",
      pressed ? "pressed" : "released", static_cast<unsigned>(point_count),
      point.x, point.y, point.pressure, static_cast<unsigned>(point.state));
  lv_label_set_text(g_touch_status, buffer);
}

void TouchpadRead(lv_indev_t* indev, lv_indev_data_t* data) {
  if (g_touch_int_flag) {
    g_touch_int_flag = false;
    g_touch.read();
    TP_Point point(0, 0, 0, 0, 0, 0);
    const uint8_t point_count = g_touch.getPointNum();
    if (point_count > 0) {
      point = g_touch.getPoint(0);
    }
    const bool pressed =
        point_count == 1 && point.pressure > 0 && point.state != 0;
    UpdateTouchStatusUnlocked(point, point_count, pressed);
    if (pressed) {
      data->state = LV_INDEV_STATE_PR;
      data->point.x =
          std::min<int>(point.x, t_panel::device::st7701::kWidth - 1);
      data->point.y =
          std::min<int>(point.y, t_panel::device::st7701::kHeight - 1);

      g_touch_last = data->point;
      return;
    }
  }

  data->state = LV_INDEV_STATE_REL;
  data->point = g_touch_last;
}

void LvglTask(void* arg) {
  printf("LvglTask start\n");
  while (true) {
    _lock_acquire(&g_lvgl_api_lock);
    uint32_t delay_ms = lv_timer_handler();
    _lock_release(&g_lvgl_api_lock);

    if (delay_ms < kLvglTaskMinDelayMs) {
      delay_ms = kLvglTaskMinDelayMs;
    } else if (delay_ms > kLvglTaskMaxDelayMs) {
      delay_ms = kLvglTaskMaxDelayMs;
    }
    usleep(delay_ms * 1000);
  }
}

lv_obj_t* CreateButton(
    lv_obj_t* parent, const char* text, lv_event_cb_t cb, void* user_data) {
  lv_obj_t* button = lv_button_create(parent);
  lv_obj_set_height(button, 40);
  lv_obj_set_style_radius(button, LV_RADIUS_CIRCLE, 0);
  lv_obj_set_style_pad_left(button, 18, 0);
  lv_obj_set_style_pad_right(button, 18, 0);
  lv_obj_set_style_bg_color(button, lv_color_hex(kColorPrimary), 0);
  lv_obj_set_style_transform_width(button, -3, LV_STATE_PRESSED);
  lv_obj_set_style_transform_height(button, -3, LV_STATE_PRESSED);
  lv_obj_set_style_bg_color(
      button, lv_color_hex(kColorPrimaryPressed), LV_STATE_PRESSED);
  lv_obj_set_style_shadow_width(button, 10, 0);
  lv_obj_set_style_shadow_opa(button, LV_OPA_20, 0);
  lv_obj_set_style_shadow_offset_y(button, 4, 0);
  lv_obj_set_style_shadow_width(button, 2, LV_STATE_PRESSED);
  lv_obj_set_style_shadow_offset_y(button, 1, LV_STATE_PRESSED);
  lv_obj_add_event_cb(button, cb, LV_EVENT_CLICKED, user_data);

  lv_obj_t* label = lv_label_create(button);
  lv_label_set_text(label, text);
  lv_obj_set_style_text_color(label, lv_color_white(), 0);
  lv_obj_center(label);
  return button;
}

lv_obj_t* CreateWrappedLabel(lv_obj_t* parent, const char* text) {
  lv_obj_t* label = lv_label_create(parent);
  lv_obj_set_width(label, LV_PCT(100));
  lv_label_set_long_mode(label, LV_LABEL_LONG_WRAP);
  lv_obj_set_style_text_font(label, &lv_font_montserrat_14, 0);
  lv_obj_set_style_text_color(label, lv_color_hex(kColorOnSurfaceVariant), 0);
  lv_label_set_text(label, text);
  return label;
}

lv_obj_t* CreateCardTitle(lv_obj_t* parent, const char* text) {
  lv_obj_t* header = lv_obj_create(parent);
  lv_obj_remove_flag(header, LV_OBJ_FLAG_SCROLLABLE);
  lv_obj_set_width(header, LV_PCT(100));
  lv_obj_set_height(header, 34);
  lv_obj_set_style_pad_all(header, 0, 0);
  lv_obj_set_style_pad_column(header, 10, 0);
  lv_obj_set_style_border_width(header, 0, 0);
  lv_obj_set_style_bg_opa(header, LV_OPA_TRANSP, 0);
  lv_obj_set_layout(header, LV_LAYOUT_FLEX);
  lv_obj_set_flex_flow(header, LV_FLEX_FLOW_ROW);
  lv_obj_set_flex_align(header, LV_FLEX_ALIGN_START, LV_FLEX_ALIGN_CENTER,
      LV_FLEX_ALIGN_CENTER);

  lv_obj_t* accent = lv_obj_create(header);
  lv_obj_remove_flag(accent, LV_OBJ_FLAG_SCROLLABLE);
  lv_obj_set_size(accent, 5, 24);
  lv_obj_set_style_radius(accent, LV_RADIUS_CIRCLE, 0);
  lv_obj_set_style_border_width(accent, 0, 0);
  lv_obj_set_style_bg_color(accent, lv_color_hex(kColorPrimary), 0);

  lv_obj_t* label = lv_label_create(header);
  lv_obj_set_width(label, 320);
  lv_label_set_long_mode(label, LV_LABEL_LONG_WRAP);
  lv_obj_set_style_text_font(label, &lv_font_montserrat_14, 0);
  lv_obj_set_style_text_color(label, lv_color_hex(kColorOnSurface), 0);
  lv_obj_set_style_text_align(label, LV_TEXT_ALIGN_LEFT, 0);
  lv_label_set_text(label, text);
  return label;
}
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
extern "C" void app_main(void) {
  printf("Ciallo\n");

  esp_lcd_panel_handle_t panel_handle = nullptr;
  if (!InitXl9535()) {
    return;
  }
  if (!InitTouch()) {
    printf("Init touch failed\n");
    return;
  }
  if (!InitTouchInterrupt()) {
    printf("Init touch interrupt failed\n");
    return;
  }
  InitEsp32h2Pins();

  printf("Init ST7701 start\n");
  if (!st7701_driver::InitSt7701(g_xl9535.get(), &panel_handle)) {
    printf("Init ST7701 failed\n");
    return;
  }
  g_panel_handle = panel_handle;
  printf("Init ST7701 done\n");
  if (!st7701_driver::InitBacklight()) {
    printf("Init backlight failed\n");
    return;
  }
  if (!InitLvgl(panel_handle)) {
    printf("Init LVGL failed\n");
    return;
  }

  st7701_driver::StartBacklightGradient(100, kBacklightFadeTimeMs);
}

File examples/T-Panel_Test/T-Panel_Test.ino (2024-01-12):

/*
 * @Description: T-Panel出厂测试程序
 * @version: V1.0.4
 * @Author: LILYGO_L
 * @Date: 2023-09-16 10:47:28
 * @LastEditors: LILYGO_L
 * @LastEditTime: 2024-01-12 18:18:37
 * @License: GPL 3.0
 */
// #define TOUCH_MODULES_GT911
// #define TOUCH_MODULES_CST_SELF
#define TOUCH_MODULES_CST_MUTUAL
// #define TOUCH_MODULES_ZTW622
// #define TOUCH_MODULES_L58
// #define TOUCH_MODULES_FT3267
// #define TOUCH_MODULES_FT5x06

#include <Arduino.h>
#include <Arduino_GFX_Library.h>
#include <Wire.h>
#include <SPI.h>
#include <SD.h>
#include <HardwareSerial.h>
#include "TouchLib.h"
#include "material_16Bit.h"
#include "pin_config.h"
#include <WiFi.h>
#include <HTTPClient.h>

#define WIFI_SSID "xinyuandianzi"
#define WIFI_PASSWORD "AA15994823428"
// #define WIFI_SSID "LilyGo-AABB"
// #define WIFI_PASSWORD "xinyuandianzi"

#define WIFI_CONNECT_WAIT_MAX (5000)

#define NTP_SERVER1 "pool.ntp.org"
#define NTP_SERVER2 "time.nist.gov"
#define GMT_OFFSET_SEC 8 * 3600 // Time zone setting function, written as 8 * 3600 in East Eighth Zone (UTC/GMT+8:00)
#define DAY_LIGHT_OFFSET_SEC 0  // Fill in 3600 for daylight saving time, otherwise fill in 0

bool Get_int = 0;
uint8_t Image_Flag = 0;
bool Touch_Flag = 0;
uint8_t Touch_Num = 0;

uint8_t Last_X = 0;
uint8_t Last_Y = 0;

HardwareSerial SerialPort1(1); // use UART1
HardwareSerial SerialPort2(2); // use UART2
char DATA1[100] = {0};

uint8_t ESP32H2_Uart_Cursor = 0;
bool Uart_Start = 0;
uint32_t Uart_Count = 0;

uint32_t cycleInterval = 0;

bool wifi_connection_failure_flag = false;
uint32_t wifi_time_delay = 0;

TouchLib touch(Wire, IIC_SDA, IIC_SCL, CST3240_Address);

Arduino_DataBus *bus = new Arduino_XL9535SWSPI(IIC_SDA /* SDA */, IIC_SCL /* SCL */, -1 /* XL PWD */,
                                               XL95X5_CS /* XL CS */, XL95X5_SCLK /* XL SCK */, XL95X5_MOSI /* XL MOSI */);
Arduino_ESP32RGBPanel *rgbpanel = new Arduino_ESP32RGBPanel(
    -1 /* DE */, LCD_VSYNC /* VSYNC */, LCD_HSYNC /* HSYNC */, LCD_PCLK /* PCLK */,
    LCD_B0 /* B0 */, LCD_B1 /* B1 */, LCD_B2 /* B2 */, LCD_B3 /* B3 */, LCD_B4 /* B4 */,
    LCD_G0 /* G0 */, LCD_G1 /* G1 */, LCD_G2 /* G2 */, LCD_G3 /* G3 */, LCD_G4 /* G4 */, LCD_G5 /* G5 */,
    LCD_R0 /* R0 */, LCD_R1 /* R1 */, LCD_R2 /* R2 */, LCD_R3 /* R3 */, LCD_R4 /* R4 */,
    1 /* hsync_polarity */, 20 /* hsync_front_porch */, 2 /* hsync_pulse_width */, 0 /* hsync_back_porch */,
    1 /* vsync_polarity */, 30 /* vsync_front_porch */, 8 /* vsync_pulse_width */, 1 /* vsync_back_porch */,
    10 /* pclk_active_neg */, 6000000L /* prefer_speed */, false /* useBigEndian */,
    0 /* de_idle_high*/, 0 /* pclk_idle_high */);
Arduino_RGB_Display *gfx = new Arduino_RGB_Display(
    LCD_WIDTH /* width */, LCD_HEIGHT /* height */, rgbpanel, 0 /* rotation */, true /* auto_flush */,
    bus, -1 /* RST */, st7701_type9_init_operations, sizeof(st7701_type9_init_operations));

void scan_i2c_device(TwoWire &i2c)
{
    Serial.println("Scanning for I2C devices ...");
    Serial.print("      ");
    for (int i = 0; i < 0x10; i++)
    {
        Serial.printf("0x%02X|", i);
    }
    uint8_t error;
    for (int j = 0; j < 0x80; j += 0x10)
    {
        Serial.println();
        Serial.printf("0x%02X |", j);
        for (int i = 0; i < 0x10; i++)
        {
            Wire.beginTransmission(i | j);
            error = Wire.endTransmission();
            if (error == 0)
                Serial.printf("0x%02X|", i | j);
            else
                Serial.print(" -- |");
        }
    }
    Serial.println();
}

void printLocalTime()
{
    struct tm timeinfo;
    if (!getLocalTime(&timeinfo))
    {
        Serial.println("Failed to obtain time");
        gfx->fillRoundRect(10, 10, 200, 80, 15, WHITE);
        gfx->setCursor(20, 40);
        gfx->setTextSize(1);
        gfx->setTextColor(RED);
        gfx->print("Failed to obtain time!");
        return;
    }
    Serial.println("Get time success");
    Serial.println(&timeinfo, "%A,%B %d %Y %H:%M:%S"); // Format Output
    gfx->fillRoundRect(10, 10, 200, 80, 15, WHITE);
    gfx->setCursor(20, 20);
    gfx->setTextSize(2);
    gfx->setTextColor(PINK);
    gfx->print(&timeinfo, " %Y");
    gfx->setCursor(20, 40);
    gfx->print(&timeinfo, "%B %d");
    gfx->setCursor(20, 60);
    gfx->print(&timeinfo, "%H:%M:%S");
}

void wifi_test(void)
{
    String text;
    int wifi_num = 0;

    gfx->setTextSize(2);
    gfx->setTextColor(GREEN);

    Serial.println("\nScanning wifi");
    gfx->printf("Scanning wifi\n");
    WiFi.mode(WIFI_STA);
    WiFi.disconnect();
    delay(100);

    wifi_num = WiFi.scanNetworks();
    if (wifi_num == 0)
    {
        text = "\nWiFi scan complete !\nNo wifi discovered.\n";
    }
    else
    {
        text = "\nWiFi scan complete !\n";
        text += wifi_num;
        text += " wifi discovered.\n\n";

        for (int i = 0; i < wifi_num; i++)
        {
            text += (i + 1);
            text += ": ";
            text += WiFi.SSID(i);
            text += " (";
            text += WiFi.RSSI(i);
            text += ")";
            text += (WiFi.encryptionType(i) == WIFI_AUTH_OPEN) ? " \n" : "*\n";
            delay(10);
        }
    }

    Serial.println(text);
    gfx->println(text);

    text = "Connecting to ";
    Serial.print("Connecting to ");
    gfx->printf("Connecting to\n");
    text += WIFI_SSID;
    text += "\n";

    Serial.print(WIFI_SSID);
    gfx->printf("%s", WIFI_SSID);
    WiFi.begin(WIFI_SSID, WIFI_PASSWORD);

    uint32_t last_tick = millis();
    uint32_t i = 0;

    while (WiFi.status() != WL_CONNECTED)
    {
        Serial.print(".");
        gfx->printf(".");
        text += ".";
        delay(100);

        if (millis() - last_tick > WIFI_CONNECT_WAIT_MAX)
        {
            wifi_connection_failure_flag = true;
            break;
        }
    }

    if (!wifi_connection_failure_flag)
    {
        text += "\nThe connection was successful ! \nTakes ";
        Serial.print("\nThe connection was successful ! \nTakes ");
        gfx->printf("\nThe connection was successful ! \nTakes ");
        text += millis() - last_tick;
        Serial.print(millis() - last_tick);
        gfx->print(millis() - last_tick);
        text += " ms\n";
        Serial.println(" ms\n");
        gfx->printf(" ms\n");

        gfx->setTextSize(3);
        gfx->setTextColor(GREEN);
        gfx->printf("\n\n\nWifi test passed!");
    }
    else
    {
        gfx->setTextSize(3);
        gfx->setTextColor(RED);
        gfx->printf("\n\n\nWifi test error!\n");
    }
}
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

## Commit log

2023-12-20 Fix compatibility of Arduino IDE
    [T-Panel_Test.ino]
2024-01-11 Fix the issue of inaccurate screen timing
    [GFX_CST3240_Image.ino, T-Panel_Test.ino]
2024-01-12 Adjust the screen backlight PWM to 1 Khz
2025-09-26 update the shell stl file #16
    [1.stl, 2.stl, 3.stl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]
2025-09-26 update the 3D diagram of the board #16
    [T-Panel_V1.2.step, T-Panel_shell.dxf]
2026-05-26 Change the T-Panel framework from Arduino framework to ESP-IDF.
    [partitions.csv]
2026-05-30 Add ESP32-S3 boot button screen rotation function
2026-08-20 fix(general_test): prevent CAN bus from stopping on transient errors
    - migrate CAN handling to TWAI Node API
    - keep CAN task running when transmit times out
    - automatically recover from bus-off state
    - use interrupt callback and queue for CAN reception
    [main.cpp]
